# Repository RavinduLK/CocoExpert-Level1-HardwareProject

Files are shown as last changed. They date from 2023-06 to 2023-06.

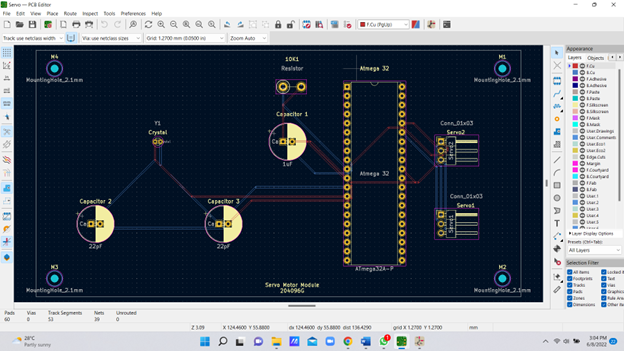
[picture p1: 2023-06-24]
Simulations/PCB Files/204096G-PCBs/204096G-PCBs'/PCB & Schematic Files-Servo/PCB Design-Screenshot.png

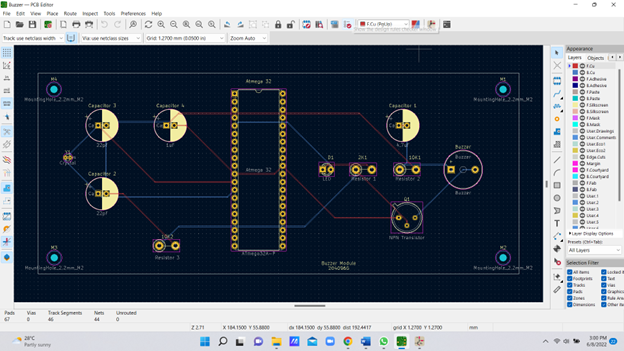
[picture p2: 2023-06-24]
Simulations/PCB Files/204096G-PCBs/204096G-PCBs'/PCB & Schematic Files-Buzzer/PCB Design-Screenshot.png

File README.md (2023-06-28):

# CocoExpert-Level1-HardwareProject
CocoExpert is an automated coconut breaking, scraping, and grinding machine with a focus on ensuring safety for housewives and frequent users, thereby eliminating the need for manual intervention

# Machine Animation Video
https://drive.google.com/drive/u/0/folders/18UEq-plaGjheWkudtf2PqrmO_yfCV39f

# Final Schematic Diagram
finale schematic diagram (2)

# Block Diagram


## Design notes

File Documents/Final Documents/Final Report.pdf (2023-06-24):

## Faculty of Information Technology

## IN 1900-ICT Project

## Automatic Coconut Breaking, Scraping, and Grinding Machine

Group No: 15

Nusky M.N.N. -204146L

Banu A.G.S. -204018X

Karunaweera R.L. -204096G

Kumarasingha H.J.A. -204108A

Lamahewage D.R. -204114M

Supervisor’s Name: BH Sudantha | Date of Submission: 01.10.2021

Dean/Senior lecturer

Dept. of Information Technology

Co-supervisor Name: Upulanka Premasiri

Lecturer

Dept. of Information Technology

Table of contents

Table of figures

Introduction

This project aims at designing an Automatic Coconut breaking, scraping, and grinding machine to

enable easy and safe extraction of milk from the coconut. Automation is one of the vital

developments which must be factored into our daily lives. The involvement of automation in the

cutting, scraping, and grinding of coconut is to improve the quality of these processes with less or

no human effort to save time and reduce the possibility of danger while cutting. There are some

existing products related to scrapping coconut in the market. In these products, there are some

limitations. Such as being unable to cut, scrape and grind the coconut in a single system. As we

are concerned about these limitations, we have come up with this machine as a solution.

Literature Survey

Traditional and Electric coconut graters

Scraping mechanism

Figure 1

This figure shows the manual coconut scraper which is used nowadays. Manually operated

coconut scraper machines are portable and may be used effectively in households, using the

clamping screw to clamp the entire mechanism securely on a table. As one rotates the manual handle,

the rotation is transferred to the scraping bit The DE husked coconut half-shell is pressed against the

sharp bit while in rotation. This device requires a fair amount of effort to grate a coconut. Attention is

required by the operator because if a slip occurs, serious injuries may result.

Figure 2

This figure shows the semi-automated coconut scraper. This machine is powered by a current,

and a switch is used to turn on and off the machine. The motor is used to rotate the scraper.

When using this machine, the operator should hold the coconut and the machine. So, in this machine also attention is required by the operator because if a slip occurs, serious injuries may

result.

Figure 3

Compared to the above two machines, the scraping part of our machine is very advantageous. Here

we use two scrapers. They work simultaneously. So, the time needed to scrap two coconuts is less

than the previous two machines. In those two machines, we should hold the coconut and the machine,

but in our scraper part, there is no need to hold the coconut and the machine. Coconuts are held by

the handles. This whole process is automated. Therefore, the operator's attention is not needed. So,

the user’s safety is confirmed.

Cutting mechanism

Figure 4

This figure shows the way we usually use to break the coconut. This is an unsafe and hard

mechanism. Also, here coconut water is wasted, and dust is spread everywhere.

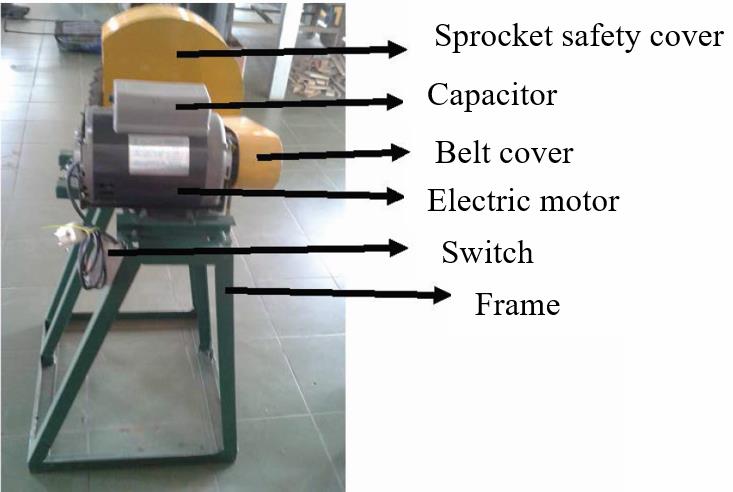
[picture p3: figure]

Figure 5

This coconut shell breaker is in the form of a box consisting of a breaking gear, and a coconut

clamp that can be adjusted according to the size of the coconut. The working principle of this

tool is the incorporation of the clamping, pressing, and shifting processes according to the

coconut fiber cutting path. The drive coconut shell breaker blade is driven by an electric motor

whose rotation has been reduced to produce a large torque. Coconut shells are the hardest part of

coconut fruit. Therefore, this shell breaker has several parts, including a sprocket safety cover,

capacitor, belt cover, electric motor as drive, switch on/off, coconut shell breaker sprocket,

coconut shell breaker and breaker, gearbox, and screw adjuster.

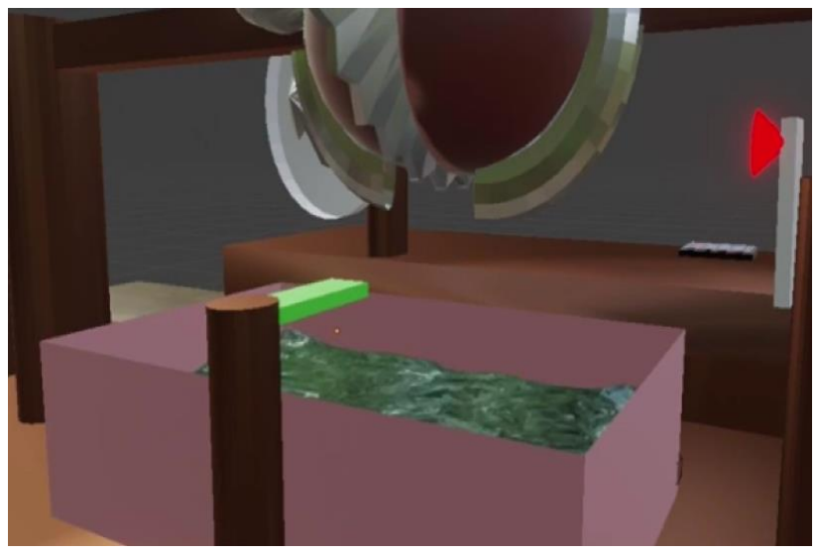
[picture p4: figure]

Figure | Figure 7 6

When compared to figure 4 the coconut breaking part of our machine is safer and easier. It is a

fully automated process. When compared to figure 5 the coconut breaking part of our machine

takes less space. Also, our breaking part is less complex. The start and end process in figure 5 is

manual but in our machine, we automated the ending process using an IR sensor. When

considering both figures 4 and 5 in our machine there is a systematic way to collect coconut

water and there is a cover to avoid coconut dust.

Also in the scrapping process, we use a color sensor. It helps to prevent the scrapping of the

coconut shell. That is also another advantage.

Summary

In our “automatic coconut breaking, scraping, and grinding machine” we improved coconut

breaking and scraping processes both by safety side and easiness. The Blender system is also

connected to the machine. Then the whole process can be done through the same machine, and it

will be very easy in our day-to-day life. The innovative automatic coconut breaking, scraping,

and grinding machine is time-saving, less power-consuming, has no need for manpower, and is

safe. It can break, scrape and grind coconuts within minutes. Also, it is portable and simple. The

coconut will be broken, scraped, and grinded automatically. The materials used for making this

machine are safe and cheap. So, among all these machines we can say our one is the most

effective machine.

Aim and objectives

Aim

- Design and develop an automated machine for the process of coconut breaking, scraping

& grinding with safety mechanisms.

Objectives

- To break the coconut and get the water separately.
- To scrape the coconut.
- To grind the coconut.
- To maintain the process safely.

Process Inputs | Outputs

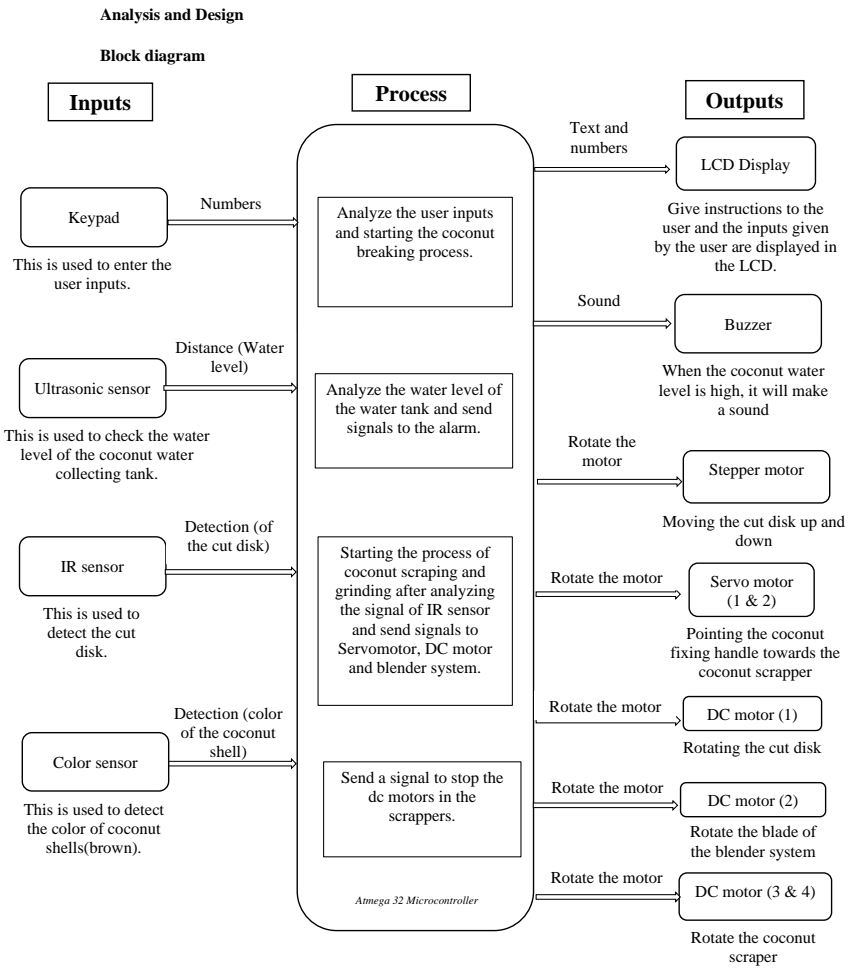
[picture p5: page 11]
Block diagram; Text and numbers; LCD Display; Atmega 32 Microcontroller; Keypad; Analyze the user inputs; Numbers; Give instructions to the; This is used to enter the; the LCD.; user inputs.; Buzzer; Sound; Distance (Water level); Ultrasonic sensor; a sound; Rotate the motor; Stepper motor; Color sensor; IR sensor; Servo motor (1 & 2); down; DC motor (3 & 4)

Analysis and Design

and starting the coconut
breaking process.

user and the inputs given
by the user are displayed in

When the coconut water
level is high, it will make

Analyze the water level of
the water tank and send
signals to the alarm.

This is used to check the water
level of the coconut water
collecting tank.

Detection (of
the cut disk)

Moving the cut disk up and

Starting the process of
coconut scraping and
grinding after analyzing
the signal of IR sensor
and send signals to
Servomotor, DC motor
and blender system.

Rotate the motor

This is used to
detect the cut
disk.

Pointing the coconut
fixing handle towards the
coconut scrapper

Detection (color
of the coconut
shell)

DC motor (1) Rotate the motor

Rotating the cut disk

Send a signal to stop the
dc motors in the
scrappers.

DC motor (2) This is used to detect
the color of coconut
shells(brown).

Rotate the blade of
the blender system

Rotate the coconut
scraper

Schematic diagram

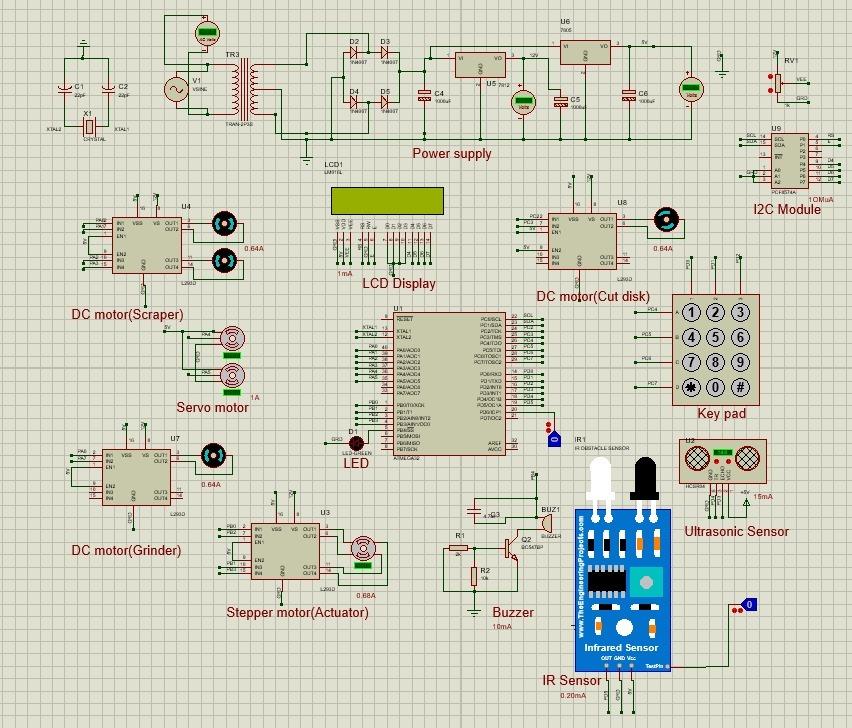
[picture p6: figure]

Figure 8 - Full schematic diagram

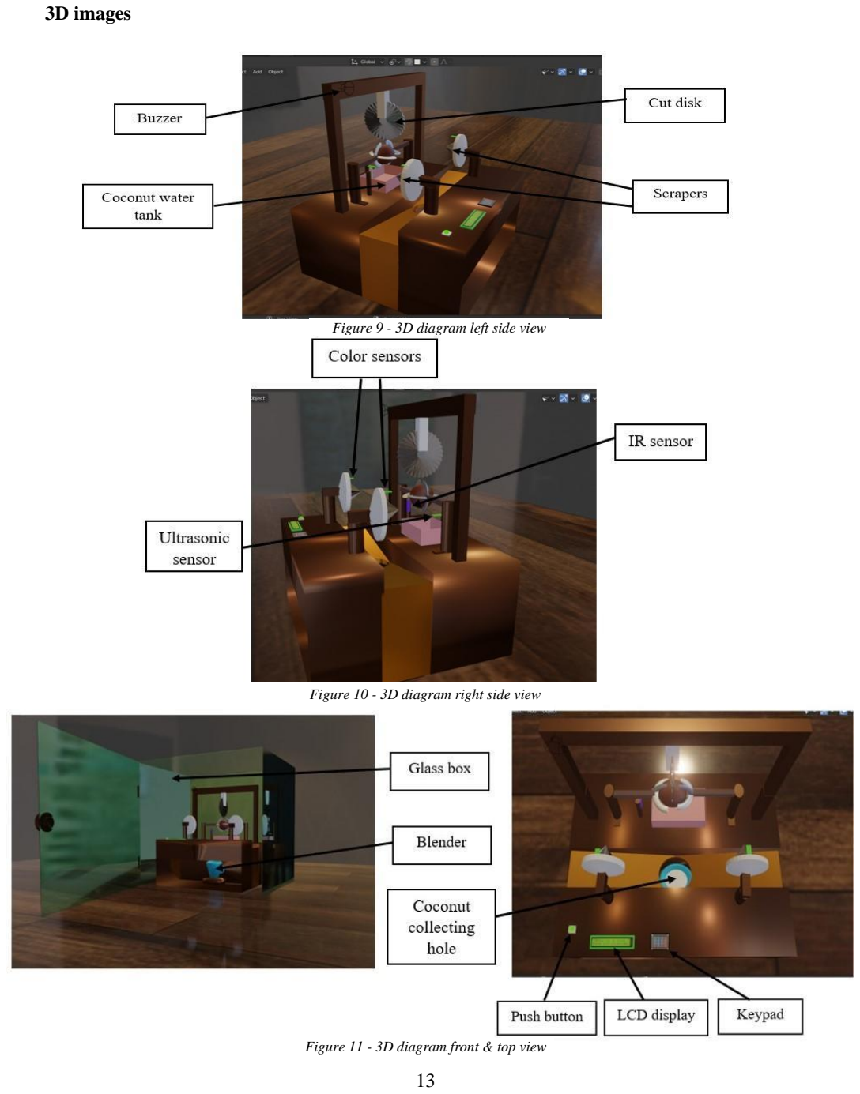
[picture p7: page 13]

3D images

Figure 9 - 3D diagram left side view

Figure 10 - 3D diagram right side view

Figure 11 - 3D diagram front & top view

Testing and Implementation

First, we should connect the machine to the power supply to power up the machine.

Using the push button user can start the machine. Once the machine starts the LCD displays the

below message.

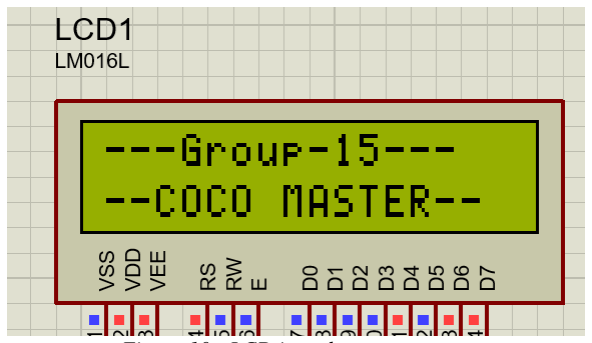
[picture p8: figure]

Figure 10 - LCD introductory message

Then the stepper motor and the DC motor begin to rotate clockwise simultaneously to break the

coconut. After the breaking part process is done, the IR sensor detects the cut disk and sends signals

to the stepper motor and the DC motor. Then only the stepper motor rotates anti-clockwise

direction and the dc motor stops rotating.

Figure 12 - Before rotating the stepper motor | Figure 11 - After rotating the stepper motor

Then the LCD will ask for the need for scraping. If scrapping is needed, the user should input

number 1 using the keypad. If not, the user should input number 2.

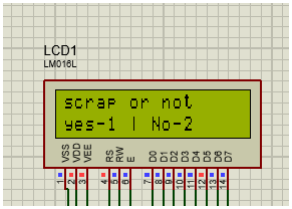
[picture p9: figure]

Figure 13 - LCD message 2

When the user inputs number 1, the display will ask whether one coconut part or both parts need

to be scrapped.

Figure 14 - LCD message 3

If the user gives number 1, only one servo motor connected to the handle will turn by 90°. After

the servo motor rotates, one DC motor connected to the scraper will rotate.

Figure 16 - Before rotating the servo motor

Figure 15 - After rotating only one servo motor

If the user gives number 2, both servo motors connected to the handles will turn by 90°. After the

servo motors rotate, both DC motors connected to the scrapers will rotate.

Figure 18 - Before rotating both servo motors

While rotating the scrapers, the color sensor connected to the scraper will detect the coconut shell

color(brown). If the brown color is detected DC motors connected to the scrappers will stop

rotating. In our simulation we used a testing pin to show the process of the color sensor.

for the brown color we assigned binary 1. for the white color we assigned binary 0.

After the scrapping part is done, the LCD displays the below message.

Figure 19 - LCD message 4

After the DC motor stops, the LCD displays the below message asking the need of grinding.

Figure 20 - LCD message 5

Figure 17 - After rotating both servo motors

If the user inputs number 1, the LCD shows the below message. The user will be given time to add

water to the grinder.

Figure 22 - LCD message 6

According to the number of scraped coconut parts, the rotating time of the DC motor in the blender

system will automatically be set by the machine. After the given time, the DC motor rotating stops.

After the grinding process the ultrasonic sensor detects the coconut water level of the coconut

water collecting tank. If the distance between the ultrasonic sensor and coconut water level is very

low, the LED will blink, and the buzzer will make a sound. The LCD also displays the below

message. Then the machine will stop.

Figure 21 - LCD message 7

Figure 23 - End of the process (LCD message and LED)

Total cost estimation

Item | Quantity | Price (Rs) | Subtotal (Rs)
Atmega32 | 1 | 1100 | 1100
IR sensor | 1 | 150 | 150
Ultrasonic sensor | 1 | 350 | 350
Buzzer | 1 | 400 | 400
Keypad (4*3) | 1 | 260 | 260
Display (2*16) | 1 | 840 | 840
Push-button | 1 | 40 | 40
Servo motor | 2 | 600 | 1200
Stepper motor | 1 | 1000 | 1000
DC motor | 4 | 1250 | 5000
Finishing | 1 | 3000 | 3000
Color sensor | 1 | 1500 | 1500
Motor driver | 4 | 780 | 3120
I2C module | 1 | 340 | 340
Total | | | 18300

Further work

- In the scrapping part, color sensor detects only the coconut shell color and stops scrappers

because sometimes coconut can be left inside the coconut shell after stopping the scrappers.

So, coconut can be wasted. As a solution we propose another automated process for the

scrappers using servo motors. If the color sensor detects the coconut shell, scrappers will

change its angle and do the scraping process until the coconut runs out.

- Sometimes users will face difficulties using the keypad to enter inputs. So, we propose a

remote-control system as further work to enter inputs more easily.

- Because of the plastic cover dust will collect inside the machine. As a solution, we propose

an automated cleaning process to remove the dust which collects inside the machine.

References

[1] ADMIN, "atmega32avr," atmega32avr, 2015. [Online]. Available: https://atmega32-avr.com/speed-direction-control-stepper-motor-using-avr-microcontroller/amp/. (https://atmega32-avr.com/speed-direction-control-stepper-motor-using-avr-microcontroller/amp/) [Accessed 15 September 2021].
[2] B. Ayob, "Atmega32-avr," [Online]. Available: https://atmega32-avr.com/servomotor-control-using-avr-atmega32-microcontroller/. (https://atmega32-avr.com/servo-motor-control-using-avr-atmega32-microcontroller/)
[3] B. Ayob, "atmega32-avr," atmega32-avr, 25 April 2012. [Online]. Available: https://atmega32-avr.com/atmega-32-pinout/. [Accessed 29 September 2021].
[4] B. Earl, "ADAFRUIT," ADAFRUIT, 5 May 2014. [Online]. Available: https://learn.adafruit.com/all-about-stepper-motors. [Accessed 15 October 2021].
[5] E. Funda, "Engineering Funda," Engineering Funda, 24 May 2021. [Online]. Available: https://www.youtube.com/watch?v=awS93t-uX4Q. [Accessed 29 October 2021].
[6] Github, "Embedotronics," Embedotronics, 2021. [Online]. Available: https://github.com/Embedotronics/Atmega16-interfacing-with-LCD-in-4-bit-mode. [Accessed 26 October 2021].
[7] l. chandak, "ElectronicWings Homepage," ElectronicWings , 2018. [Online]. Available: https://www.electronicwings.com/avr-atmega/ultrasonic-module-hc-sr04-interfacing-with-atmega1632. (https://www.electronicwings.com/avr-atmega/ultrasonic-module-hc-sr04-interfacing-with-atmega1632.) [Accessed 23 October 2021].
[8] l. chandak, "ElectronicWings Homepage," ElectronicWings Homepage, 2018. [Online]. Available: https://www.electronicwings.com/avr-atmega/interfacing-lcd-16x2-in-4-bit-mode-with-atmega-16-32-. (https://www.electronicwings.com/avr-atmega/interfacing-lcd-16x2-in-4-bit-mode-with-atmega-16-32-.) [Accessed 16 September 2021].
[9] TUSHAR, "Embedds," Embedds, 2018. [Online]. Available: https://embedds.com/interfacing-dc-motor-to-atmega32/. [Accessed 25 September 2021].
[10] Unknown, "Wikipedia," Wikipedia, 21 August 2021. [Online]. Available: https://en.wikipedia.org/wiki/DC_motor. [Accessed 15 October 2021].

Figure 24 - Ultrasonic sensor

Individual contribution

Member 1: Nusky M.N.N. (204146L)

Responsible Part:

My responsible components are the Ultrasonic sensor module and LCD Display module. I have

done the designing of schematic diagrams, PCB designs, and C codes for the above two modules.

And I made the full code of our machine. Also, I contributed to making the reports, 3D design of

our machine and presentations as well.

### 1. Ultrasonic sensor

Technique:

In our project, we used ultrasonic sensor to identify whether coconut water tank overflow or not.

We fixed ultrasonic sensors in the 10 cm height above the tank. When a distance (height) below

15 cm, an ultrasonic sensor is given a signal to the buzzer, and it will be given to signal to the

display.

Specifications:

- Working voltage: 5V DC
- Working current: 15mA
- Distance range: 2 - 400cm
- Measuring angle: 15 degrees
- Trigger input pulse: 10 micro-seconds

Ultrasonic sensor

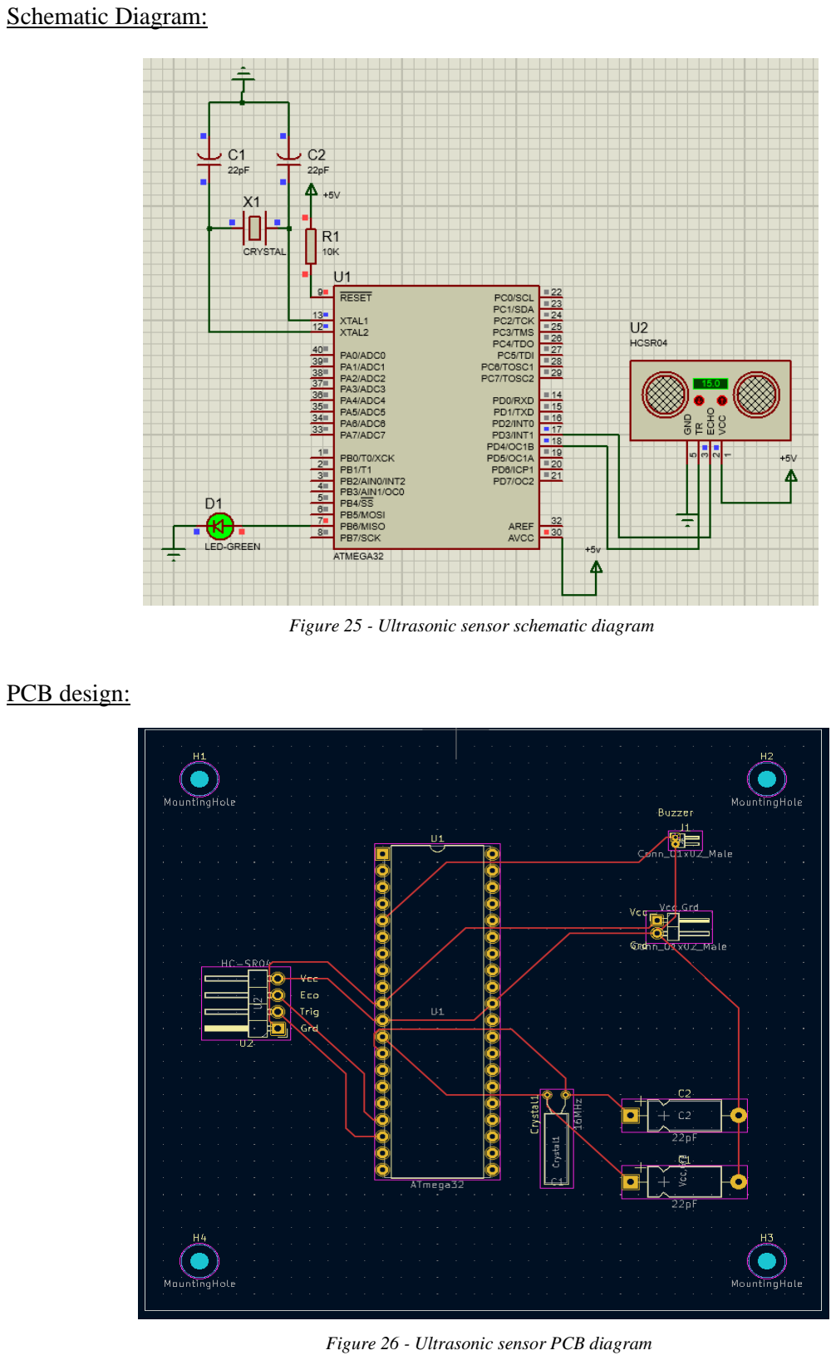
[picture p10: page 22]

Figure 25 - Ultrasonic sensor schematic diagram

Figure 26 - Ultrasonic sensor PCB diagram

Schematic Diagram:

PCB design:

Code:

#define F_CPU 8000000UL

#include <avr/interrupt.h> #include <util/delay.h>

#include <stdlib.h>

#include <avr/io.h>

static volatile unsigned int tCount = 0; static volatile int i = 0;
double distance = 0;
int main(void)
{

UBRRH=0x00;
UBRRL=51;
DDRB = DDRB | 1 << DDB6;
DDRD = DDRD | 1 << DDD4;
DDRD = DDRD & ~(1 << DDD3) ; PORTD = PORTD & ~(1 << PD3); _delay_ms(50);
GICR |= 1<<INT1;
MCUCR |= 1<<ISC10;
TIMSK |= 1 << TOIE1;
sei();
while(1)
{
PORTD = PORTD | 1<<PD4;
_delay_us(15);
PORTD = PORTD &
~(1<<PD4);
_delay_us(15);
distance =
tCount*1000000.0/F_CPU/58; if (distance < 15)
{
PORTB = PORTB | 1 <<
PB6;
}

else
{
PORTB = PORTB & ~(1 <<
PB6);
}
_delay_ms(200);
}
}
ISR(INT1_vect)
{
if(i == 0)
{
TCCR1B |= 1<<CS10;
i = 1;
}
else
{
TCCR1B = 0;
tCount = TCNT1;
TCNT1 = 0;
i = 0;
}
}

ISR(TIMER1_OVF_vect){
TCCR1B = 0;
tCount = 200;
TCNT1 = 0;
i = 0;
}

Figure 27

### 2. LCD display

Technique:

In our project we use a LCD display (16*2) for displaying what the process is at the time on our

machine and get the input from the user at a specific time.

E.g. | 1. Do you want to scrape?
| 2.How many parts scrape?
| 3.Do you want to grind?

Specification:

- Operating voltage of the LCD is 4.7V – 5.3V
- The utilization of current is 1mA with no backlight
- The display bezel is 72 x 25mm
- Number of columns – 16
- Number of rows – 2.
- It can display 32 characters at time

### 3. I2c Module (PCF8574A)

Technique:

In our project we used I2c module (PCF8574A) to reduce number of LCD pins which are

connected to the microcontroller with 2 pins.

Specification:

- Number of input outputs | -8
- Features | -Interrupt pin
- Supply voltage | -2.5V-6V
- Low standby-current consumption of 10 μA max.
- Addresses | -8
- Frequency (Max) | -100kHz
- Operating temperature range (C) | -40 to 85

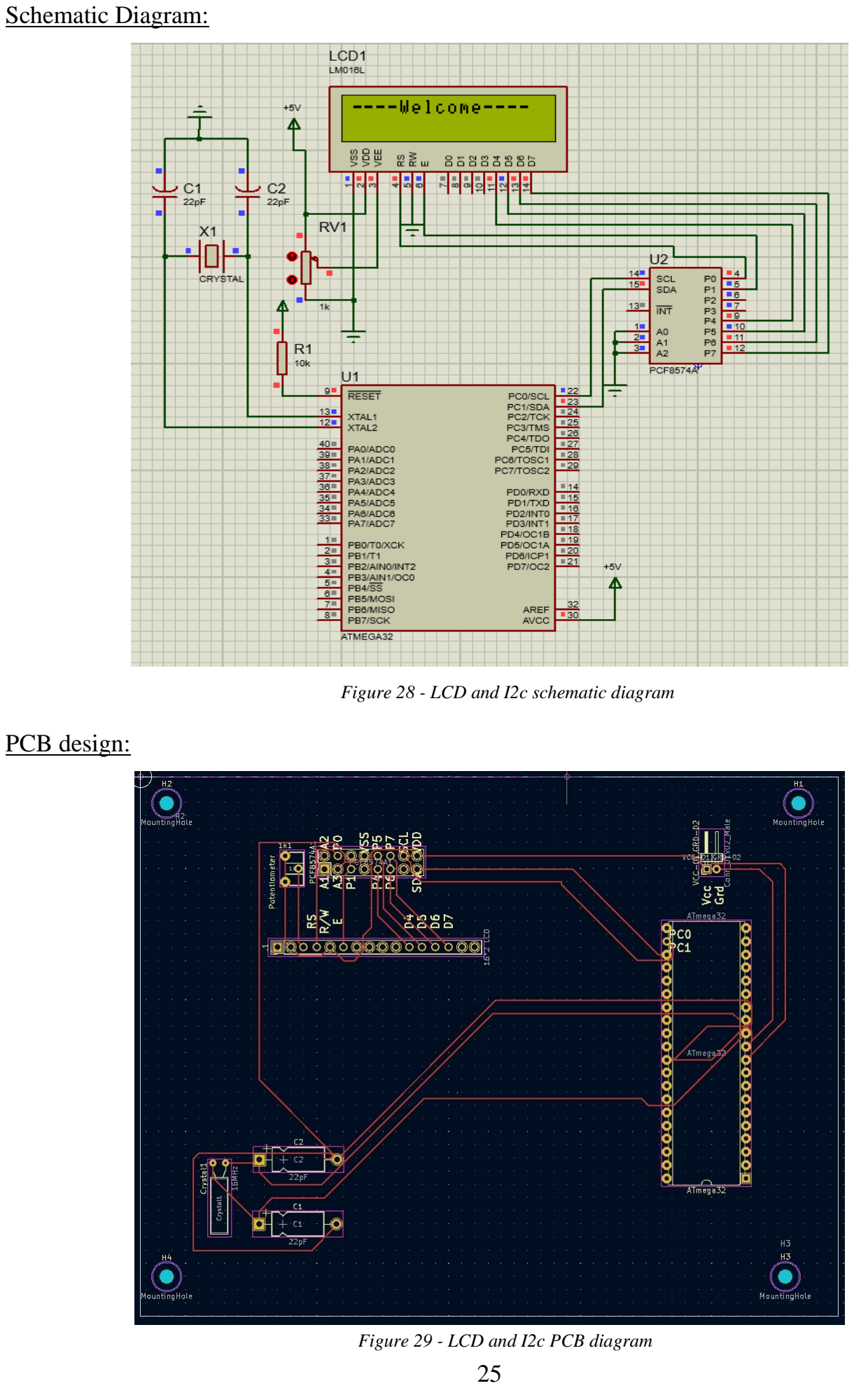
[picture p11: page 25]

Figure 28 - LCD and I2c schematic diagram

Figure 29 - LCD and I2c PCB diagram

Schematic Diagram:

PCB design:

Code:

#define F_CPU 8000000UL

#include <avr/io.h>

#include <util/delay.h>

#include "i2c.h"

#include "LCD_I2C.h"

int main(void)
{
i2c_init();
i2c_start();
i2c_write(0x70);
lcd_init();
while (1)

{
lcd_cmd(0x80);
lcd_msg("----Welcome----"); _delay_ms(1000);
lcd_cmd(0x01);
_delay_ms(100);
lcd_msg("scrap or not");
lcd_cmd(0xC0);
_delay_ms(200);
lcd_msg("yes-1 | No-2");
_delay_ms(1000);
lcd_cmd(0x01);
_delay_ms(200);
lcd_msg("How many parts?"); lcd_cmd(0xC0);
_delay_ms(200);
lcd_msg("One-1 | Two-2");
_delay_ms(1000);
lcd_cmd(0x01);
lcd_msg("--Thank you!--"); _delay_ms(1000);
lcd_cmd(0x01);
_delay_ms(1000);

}
}

Member 2: Banu AGS (204018X)

Responsible part:

- Designed, tested, and implemented steppe motor systems.
- designed the power supply system
- used the blender software to create the animation of the machine

In our project I have took the responsibility of moving the cut disk by using a stepper motor and a

motor driver. I’ve used stepper motor as it has Flexibility and supplied a constant holding torque

without the need for the motor to be powered. I've designed the schematic diagram of power supply

and stepper motor using proteus software. And used Atmel studio to program the stepper motor.

To create the PCB designs for my modules I've used the Kicad software. And I've helped in 3D

design and animation of the machine using the Blender software.

### 1. Stepper motor

Technique:

We're using a NEMA-17 stepper motor to move the cut disk. When the stepper motor rotates

clockwise the cut disk system attached to the stepper motor shaft moves down towards the coconut.

After breaking the coconut, the IR sensor gives a signal to the stepper motor, and it will rotate anti-

clockwise. Then the cut disk moves upwards to the starting position.

Specifications:

- Working voltage – 12V
- Max current – 1.58A
- Holding torque -6.0kg-cm(85oz-in)
- step angle -200 steps/revolution
- Bi-polar stepper motor | Figure 30 - Stepper motor

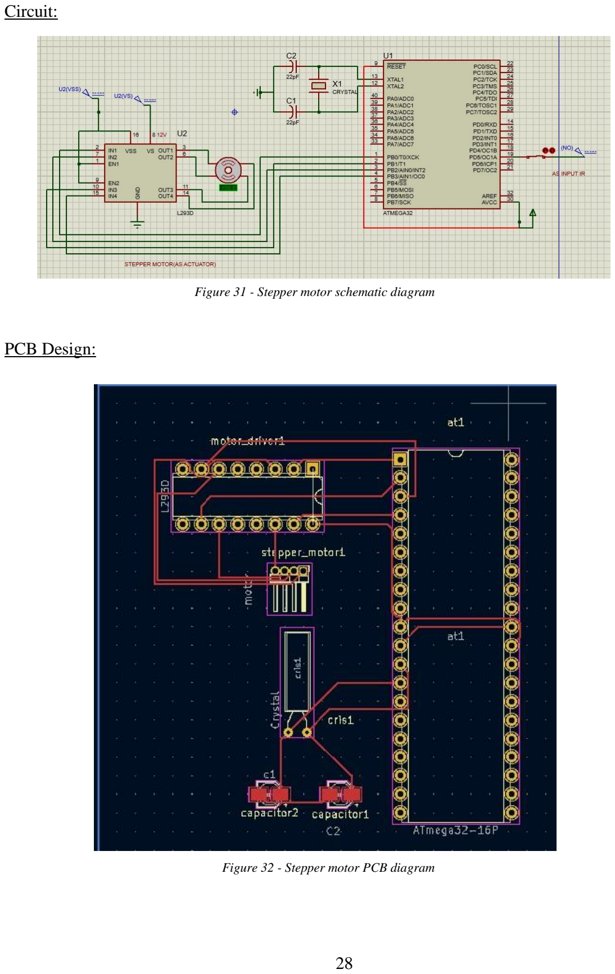
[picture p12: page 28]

Circuit:

PCB Design:

Figure 31 - Stepper motor schematic diagram

Figure 32 - Stepper motor PCB diagram

Code:

### 1. L293D Driver

Technique:

I have used an l293d driver to control the current flow through the stepper motor. Also, the

direction of this motor can be controlled independently.

Specification:

- Motor voltage Vcc2 (VS): 4.5V to 36V
- Supply Voltage to Vcc1(VSS): 4.5V to 7V
- Maximum Peak motor current: 1.6A
- Speed and Direction control is possible

#define F_CPU 8000000UL /* Define CPU Frequency 8MHz */

#include <avr/io.h> /* Include AVR std. library file */

#include <util/delay.h> /* Include delay header file */

int main(void)
{
int period=100;
DDRB |= 0B00001111;// making pins as output for stepper motor
DDRD &= ~(1<<5) ; //AS IR INPUT
while (1)
{
/* Rotate Stepper Motor clockwise*/ if(!(PIND & 0b00100000)) // ir not detected {
//power each winding in order to rotate PORTB = 0B00001000;
_delay_ms(period);
PORTB = 0B00000100;
_delay_ms(100);
PORTB = 0B00000010;
_delay_ms(100);
PORTB = 0B00000001;
_delay_ms(period);
}

/* Rotate Stepper Motor Anticlockwise */ else if((PIND & 0b00100000)) // ir detected {
for(int i=0;i<25;i++)
{PORTB = 0B00000001;
_delay_ms(period);
PORTB = 0B00000010;
_delay_ms(period);
PORTB = 0B00000100;
_delay_ms(100);
PORTB = 0B00001000;
_delay_ms(period);}
}
}
}

### 1. Power supply

Technique:

In our project we’re using a power supply system to power up the components. I have used an ac

step down transformer to convert ac 240v to 20v as our system requires a maximum voltage of

12V (to overcome current fluctuation issues I've taken 20V). Then used a rectifier circuit with 4

diodes to rectify the AC output from the transformer to DC. The capacitor is used as a filter to

remove the ripples from the rectified DC signal. Ripples are AC components in the DC signal.

Capacitor filters those AC components and provides a stable DC. I’ve used voltage regulators to

provide the regulated output. In our project we need only 5v and 12v, so I selected 7805,7812

regulators to fill the requirements.

Circuit:

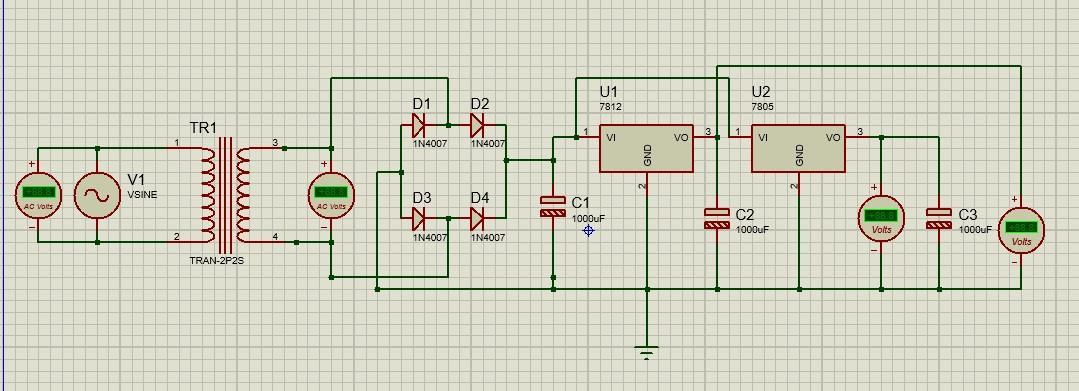
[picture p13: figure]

PCB Design:

Figure 33 - Power supply schematic diagram

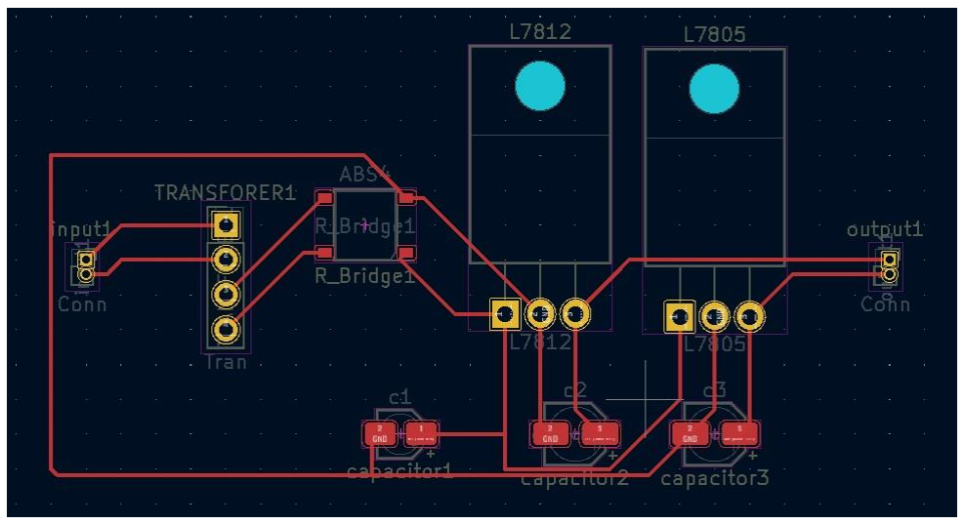
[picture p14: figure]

Figure 34 - Power supply PCB diagram

Member 3: Karunaweera R.L. (204096G)

Responsible Part:

My responsible components are the servo motor module and buzzer module. I have done the

designing of schematic diagrams, PCB designs, and C codes for the above two modules. And I

made the full PCB design of our machine. Also, I contributed to making the reports, presentations,

and presenting as well.

### 1. Servo Motor

Technique:

Servo motor controls the fixing handles and points the coconut fixing handle towards the scraper

by turning it by 90 degrees and holding it thereafter coconut breaks till the coconut scraping is

finished as you can see in the below figures. And I selected SG Tower pro 90 Motor for our project.

Figure 36

Specifications:

- The operating Voltage is +5V typically.
- Torque is 2.5kg/cm.
- The operating speed is 0.1s/60°.
- Gear Type is Plastic.
- Rotation is 0°-180°.
- Weight of motor is 9gm.
- The package includes gear horns and screws.

Figure 35

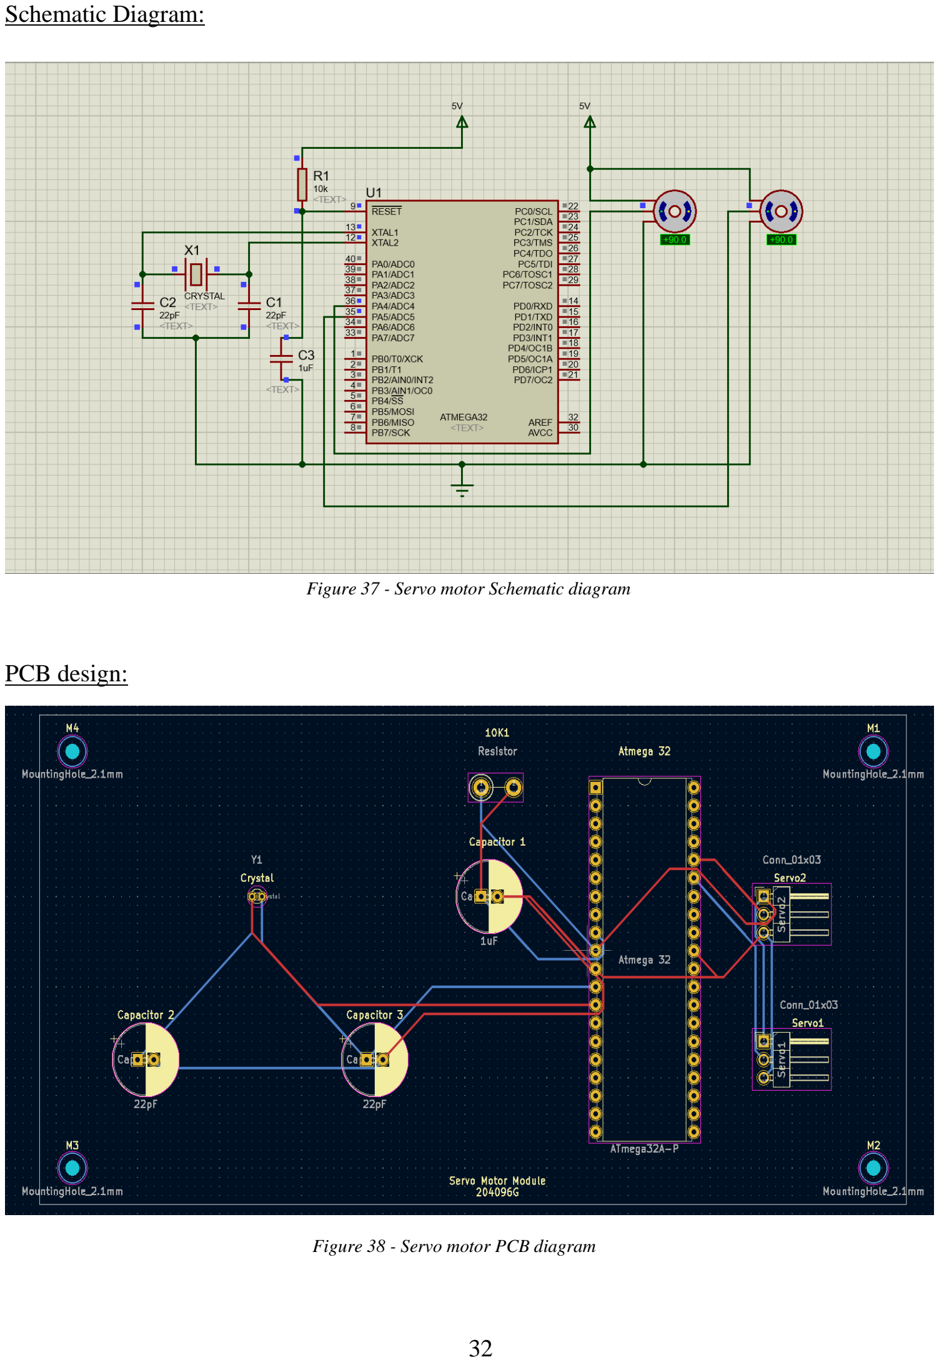
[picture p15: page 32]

Schematic Diagram:

PCB design:

Figure 37 - Servo motor Schematic diagram

Figure 38 - Servo motor PCB diagram

Codes:

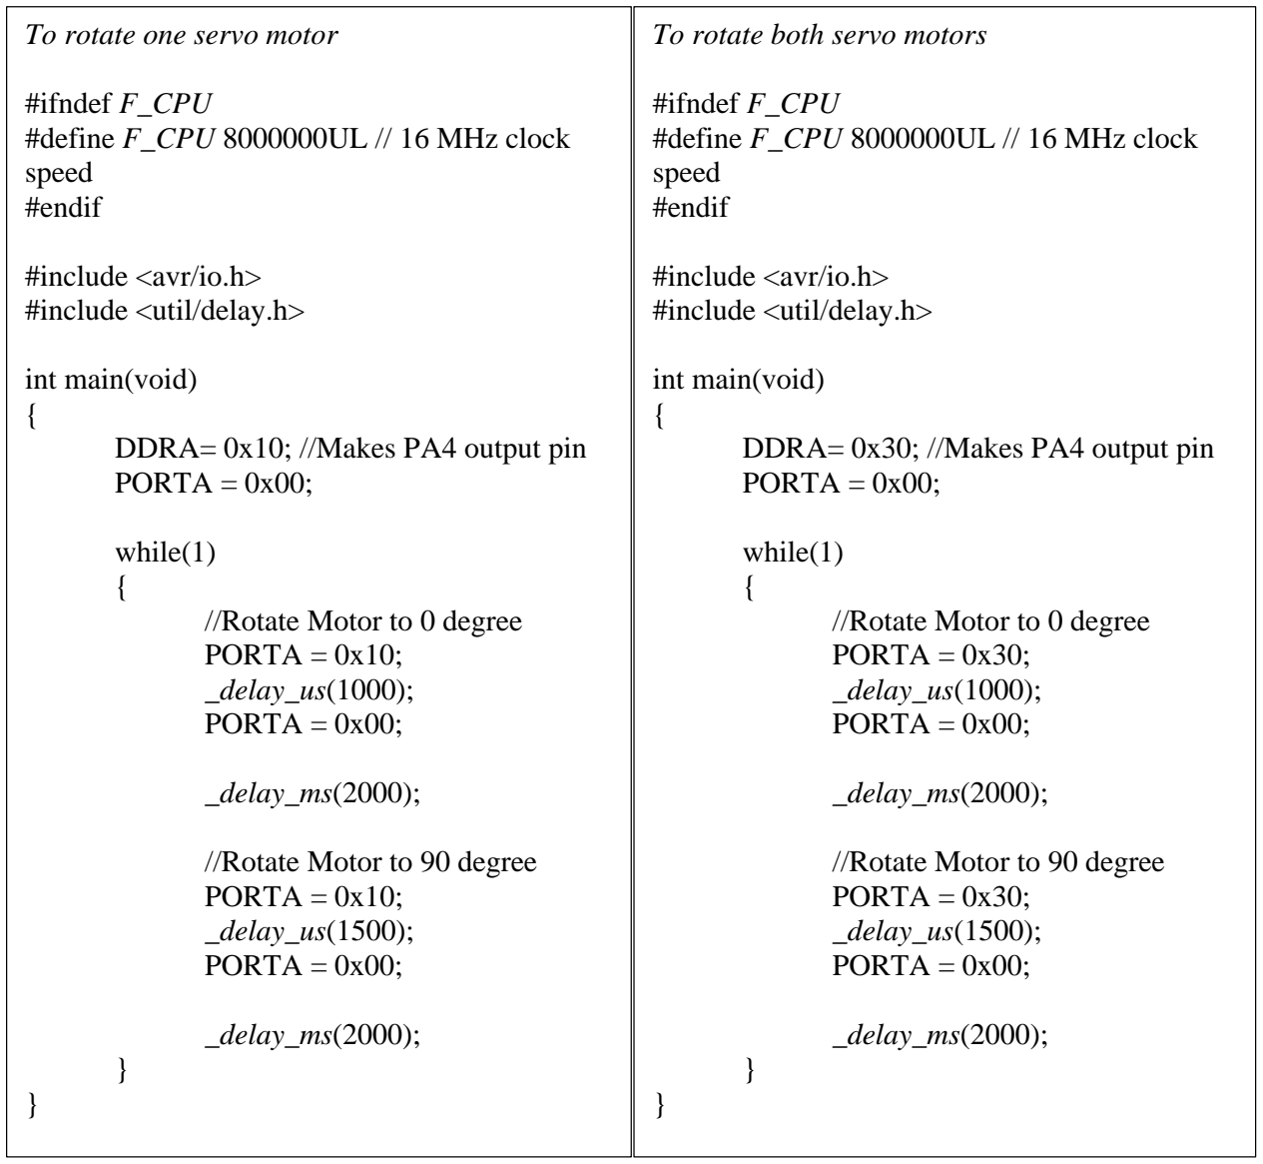
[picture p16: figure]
Figure; To rotate one servo motor; #ifndef F_CPU #define F_CPU 8000000UL // 16 MHz clock speed #endif; #include <avr/io.h> #include <util/delay.h>; int main(void) {; DDRA= 0x10; //Makes PA4 output pin PORTA = 0x00;; while(1) {; //Rotate Motor to 0 degree PORTA = 0x10; _delay_us(1000); PORTA = 0x00;; _delay_ms(2000);; //Rotate Motor to 90 degree PORTA = 0x10; _delay_us(1500); PORTA = 0x00;; To rotate both servo motors; DDRA= 0x30; //Makes PA4 output pin PORTA = 0x00;; //Rotate Motor to 0 degree PORTA = 0x30; _delay_us(1000); PORTA = 0x00;; //Rotate Motor to 90 degree PORTA = 0x30; _delay_us(1500); PORTA = 0x00;

### 2. Buzzer

Technique:

The purpose of using the buzzer in our machine is to notify the user if the coconut water tank is

full. So based on the signal of the ultrasonic sensor it will ring. If the ultrasonic sensor senses the

water level is high, then it will send a signal through the microcontroller and the buzzer will start

to ring. That is shown in the below picture.

Specifications:

- Rated Voltage is 6V DC
- Operating Voltage is 4-8V DC
- Rated current is less than 30mA
- Sound Type is Continuous Beep
- Resonant Frequency is 2300 Hz

Figure 39

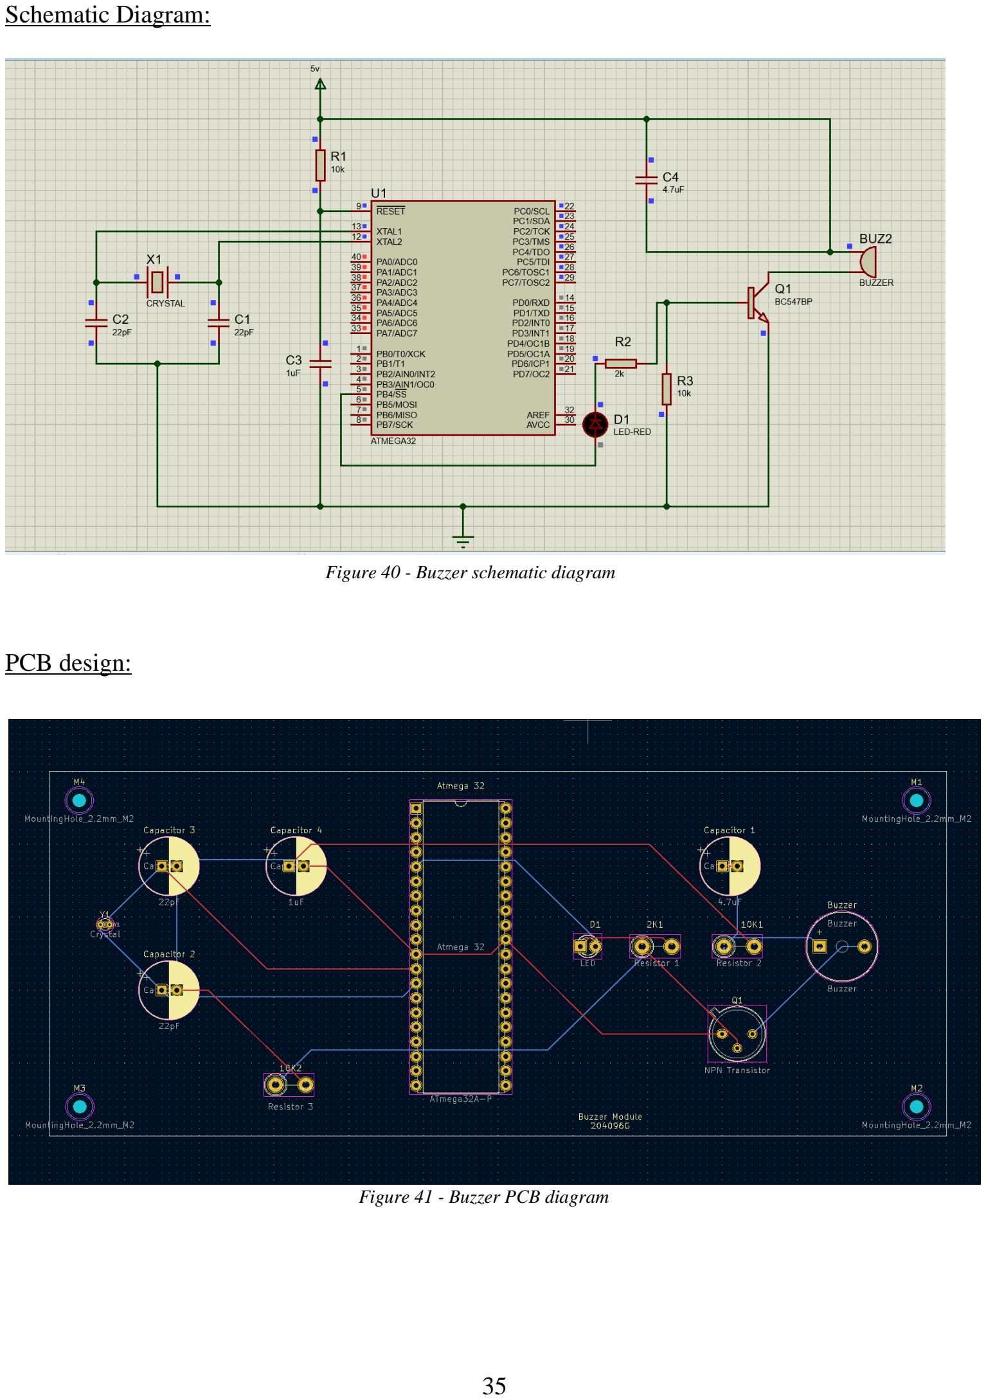
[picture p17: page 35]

Schematic Diagram:

PCB design:

Figure 41 - Buzzer PCB diagram

Figure 40 - Buzzer schematic diagram

Compiled Code:

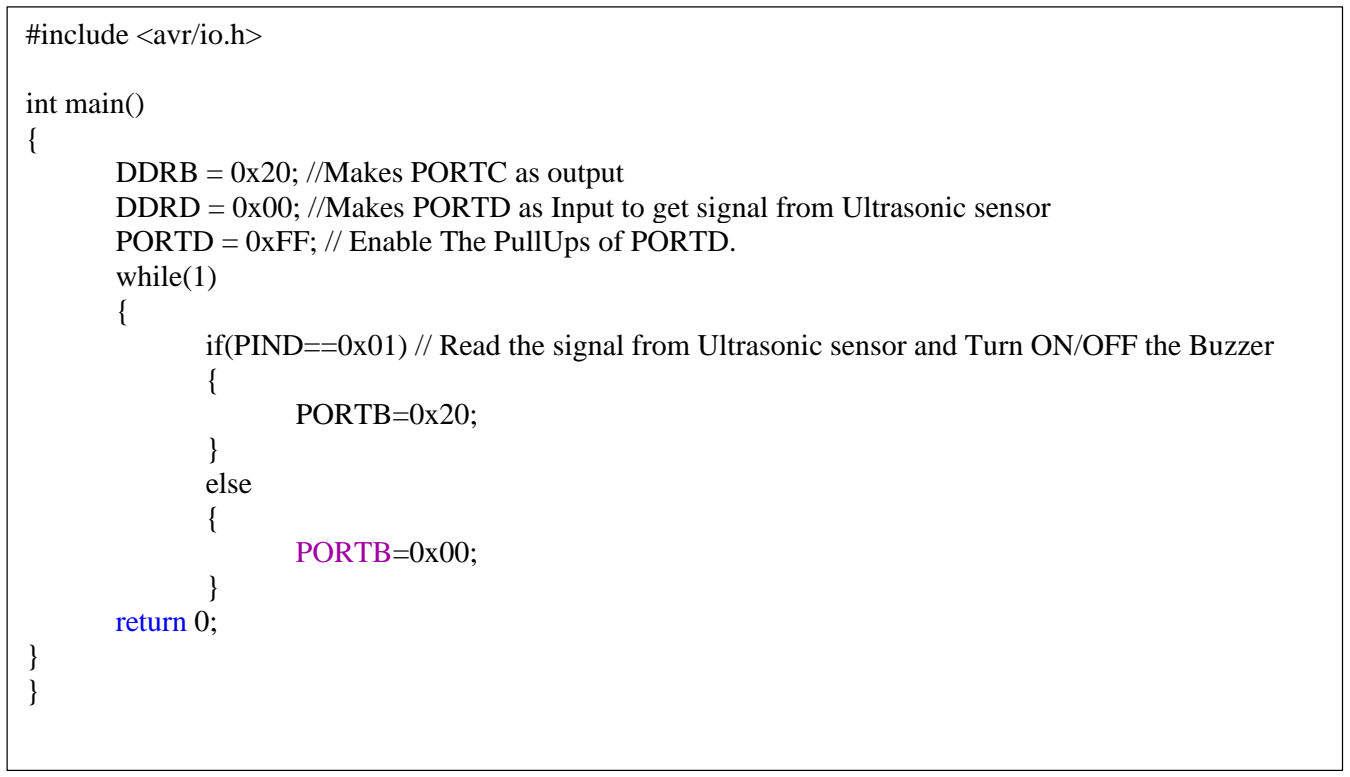
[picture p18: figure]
Figure; #include <avr/io.h>; int main() {; DDRB = 0x20; //Makes PORTC as output; while(1) {; PORTB=0x20;; } else {; PORTB=0x00;; } return 0;

DDRD = 0x00; //Makes PORTD as Input to get signal from Ultrasonic sensor PORTD = 0xFF; // Enable The PullUps of PORTD.

if(PIND==0x01) // Read the signal from Ultrasonic sensor and Turn ON/OFF the Buzzer

Member 4: Kumarasingha H.J. A. (204108A)

Responsible Part:

My responsible components are the DC motor module and color sensor module. I have done the

designing of schematic diagrams, PCB designs, and C codes for the above two modules. Also, I

contributed to making the reports, presentations, and presenting as well.

### 1. DC motor

Technique:

A dc motor converts direct current electrical energy into mechanical energy. The machine uses dc motors to rotate the cut disk, blender, and the scrappers by 360°
.There are 3 main types of dc

motors. dc shunt motor, dc series motor and dc compound motor. The shunt motor is more suitable

for the scrappers because the speed of a dc shunt motor is sufficiently constant. A compound dc

motor is more suitable for cut disk because compound motors provide high starting torque and

good speed regulation.

Specifications:

- Maximum Voltage - 12V
- Maximum Current - 0.64A
- Rated Speed (RPM) -200
- Rated Torque(kg-cm) -1.5
- Stall Torque(kg-cm) - 5.4

Circuit:

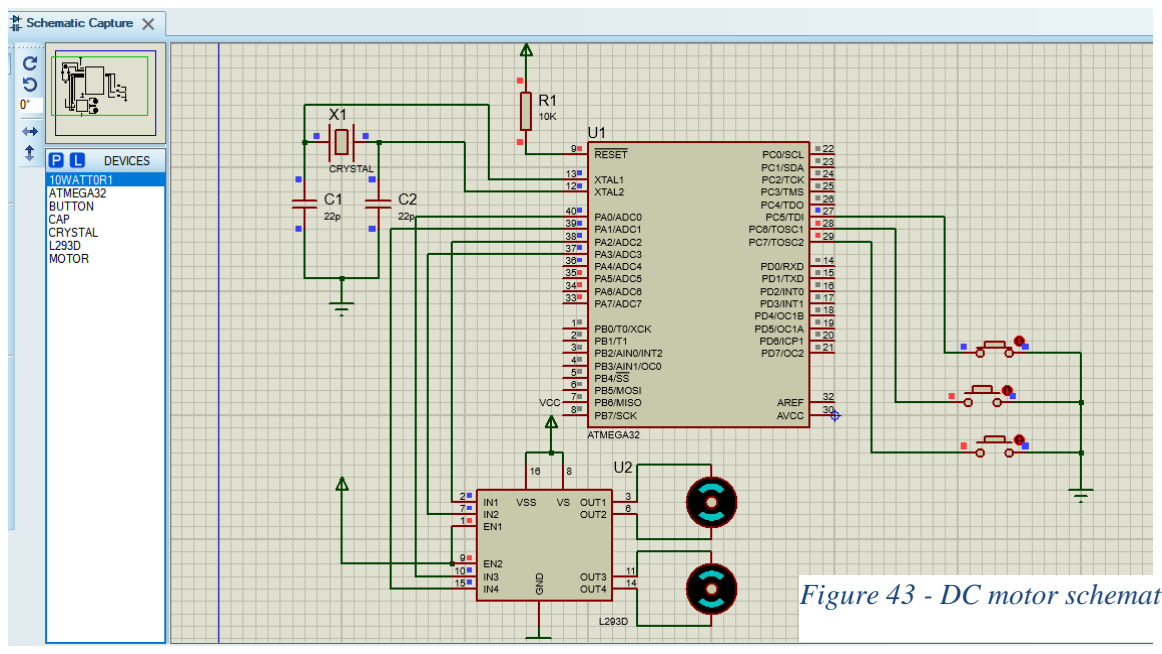
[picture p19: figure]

Figure 43 - DC motor schematic diagram of scrapers

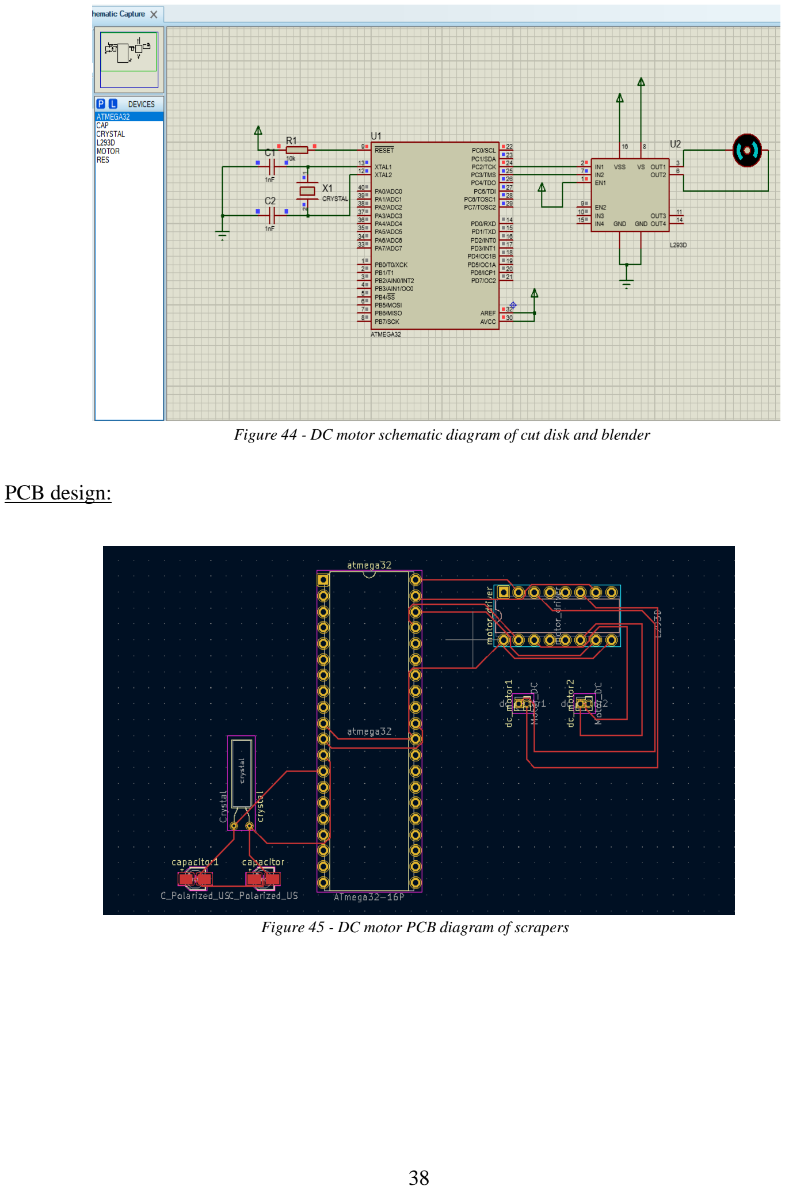
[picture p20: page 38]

PCB design:

Figure 44 - DC motor schematic diagram of cut disk and blender

Figure 45 - DC motor PCB diagram of scrapers

Figure 46 - DC motor PCB diagram of cut disk and blender

Code:

// code for the scrapers

#include <avr/io.h>

#define F_CPU 16000000UL

#include "util/delay.h"

//Test the PINC7
#define white_both (PINC&0b10000000) //Test the PINC6

#define brown (PINC&0b01000000) //Test the PINC5

#define white_one (PINC&0b00100000) //OUTPUT DATA FOR MOTOR

#define run_both 0b11100101

#define stop_running 0b11100000 #define run_one_motor 0b11100001 int main(void){

DDRA=0b00011111;//PINC7.5 INPUT PORTC=0b11100000; //PC7.5 SET TO HIGH while (1) {
if (white_both==0){
PORTA=stop_running;
_delay_ms(100);
PORTA=run_both;
}

else if (brown==0){
PORTA=stop_running;
_delay_ms(100);
PORTA=stop_running;
}
else if (white_one==0){
PORTA=stop_running;
_delay_ms(100);
PORTA=run_one_motor;
}
}

### 2. Color sensor

Technique:

It can Detect color of an object. Color converts the intensity of incident radiation into frequency.

This is used to detect the color of coconut shells(brown) in the

machine.

Specifications:

- Working voltage: 2.7 - 5.5v
- Working current: 1.4 mA
- Dimension: 28.4 x 28.4 mm
- Interface: digital TTL
- Weight: 4.17g
- Programmable color

// code for the cut disk and blender

#ifndef F_CPU

#define F_CPU 16000000UL // 16MHz clock speed #endif

#include <avr/io.h> //standard AVR library #include <util/delay.h> // delay library

int main(void){
DDRC= 0XFF; //direction of port B as output
while(1) // infinite loop{
PORTC= 0X05; //motor rotation in clockwise direction _delay_ms(2000); //delay of 2 sec

PORTC = 0X00; // motor stopped _delay_ms(2000); // delay of 2 sec }
}

Figure 47 - Color sensor

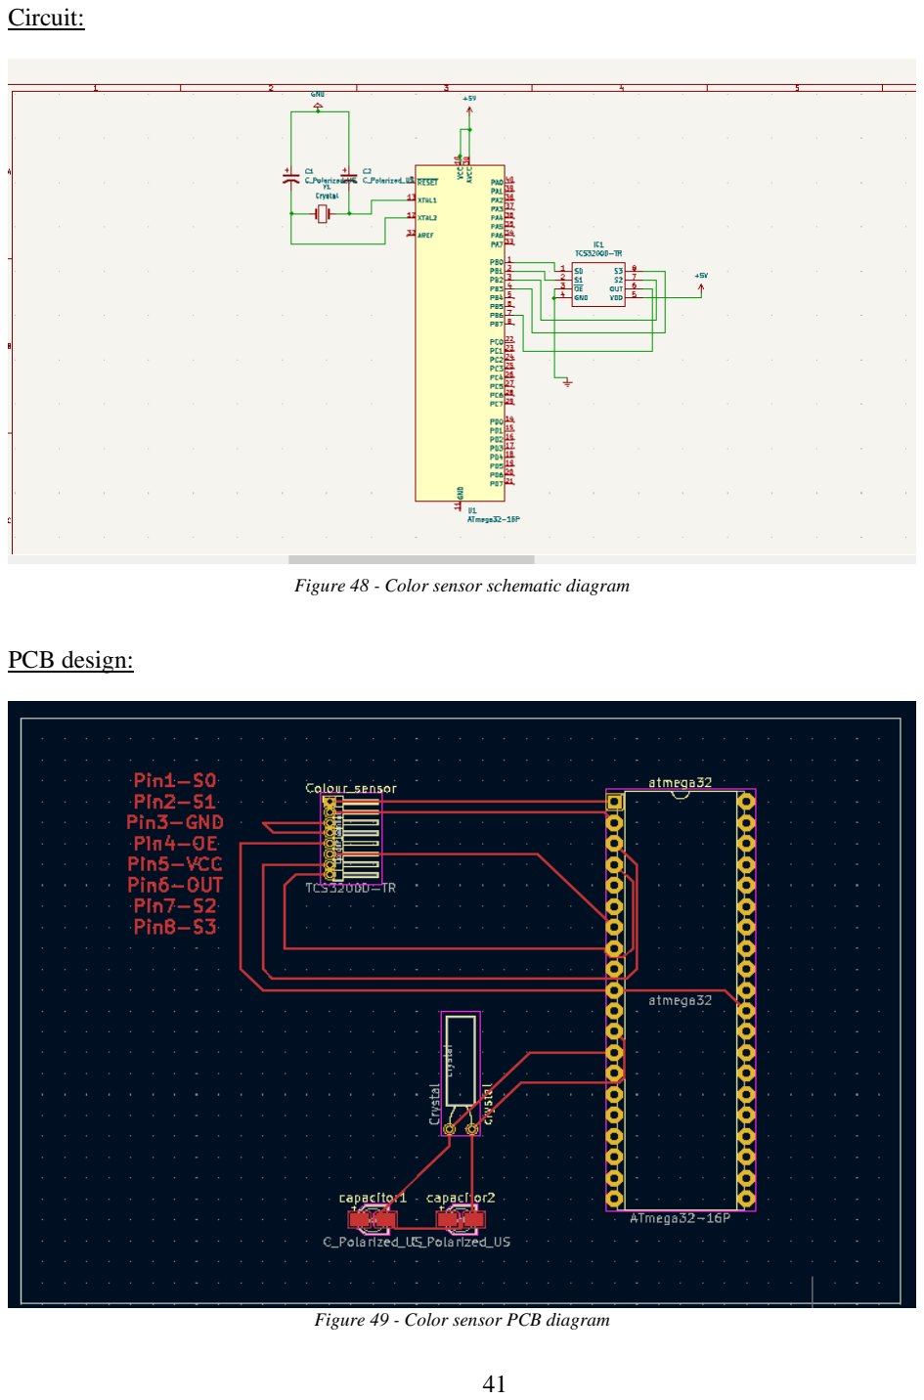
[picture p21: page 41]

Circuit:

PCB design:

Figure 48 - Color sensor schematic diagram

Figure 49 - Color sensor PCB diagram

Code:

#include <avr/io.h>

#include <util/delay.h>

#include "lib/colour_sensor/tcs3200.h"

uint32_t MeasureR(); //measure frequency with red filter uint32_t MeasureG(); //measure frequency with green filter uint32_t MeasureB(); //measure frequency with blue filter uint32_t MeasureC(); //measure frequency without filter int main(void){
InitTCS3200(); //Initialize TCS Library
uint8_t x=0;
int8_t vx=1;
while(1){
TCSLEDOn();
uint32_t v1=MeasureC();
delay_ms(100);

TCSLEDOff();
uint32_t v2=MeasureC();

uint32_t d=v1-v2;

if(d>8000) //detect colour change{ if(colour==red){
//stop motor
}
else if (colour==white){
//rotate motor
}
uint32_t r,g,b; //Show
TCSLEDOn();
r=MeasureR();
g=MeasureG();
b=MeasureB();
TCSLEDOff();
uint32_t smallest;

if(r<b){
if(r<g)
smallest=r;
else
smallest=g;
}

Else{
if(b<g)
smallest=b;
else
smallest=g;
}
uint32_t _r,_g,_b;
smallest=smallest/10; //decrease the smallest value with factor of 10 _r=r/smallest; //r, g, b are the value which have scaled
_g=g/smallest;
_b=b/smallest;
} } }
uint32_t MeasureR(){
TCSSelectRed();
uint32_t r;
_delay_ms(10);
r=TCSMeasure();
_delay_ms(10);
r+=TCSMeasure();
_delay_ms(10);
r+=TCSMeasure();
return r/3.3;
}
uint32_t MeasureG(){
TCSSelectGreen();
uint32_t r;
_delay_ms(10);
r=TCSMeasure();
_delay_ms(10);
r+=TCSMeasure();
_delay_ms(10);
r+=TCSMeasure();
return r/3;
}
uint32_t MeasureG(){
TCSSelectGreen();
uint32_t r;
_delay_ms(10);
r=TCSMeasure();
_delay_ms(10);
r+=TCSMeasure();
_delay_ms(10);
r+=TCSMeasure();
return r/3; }

### 3. L293D motor driver

Technique:

Output voltage and current of microcontroller is not sufficient to drive a dc motor. So, in the

machine l293d motor drivers provide up to 600mA current in the voltage range from 4.5 to 36V

to drive a dc motor.

Specifications:

- Wide Supply-Voltage Range: 4.5 V to 36 V
- Separate Input-Logic Supply
- Output Current :600 mA Per Channel
- High-Noise-Immunity Inputs

uint32_t MeasureB(){
TCSSelectBlue();
uint32_t r;
_delay_ms(10);
r=TCSMeasure();
_delay_ms(10);
r+=TCSMeasure();
_delay_ms(10);
r+=TCSMeasure();
return r/4.2; }

uint32_t MeasureC(){
TCSSelectClear();
uint32_t r;
_delay_ms(10);
r=TCSMeasure();
_delay_ms(10);
r+=TCSMeasure();
_delay_ms(10);
r+=TCSMeasure();
return r/3;
}
}

Figure 50 - Motor driver

Member 5: Lamahewage D. R. (204114M)

Responsible part:

My responsible components are the servo motor module and buzzer module. I have done the

designing of schematic diagrams, PCB designs, and C codes for the above two modules. Also, I

contributed to making the reports, presentations, and presenting as well.

### 1. IR sensor

Technique:

There are two LEDs. one of them emits IR Ray. the other receives IR rays. if that IR ray touches

any surface, it reflects. Then the reflected IR ray is caught by the IR receiver. then the sensor sends

a signal to fulfill our need. In our project, the IR sensor is

used to detect the cut disk.

Specifications:

- Working voltage: 3.6 - 5v
- Working current: 20mA
- Distance range: 2cm - 30cm
- Dimensions: 48 * 14 * 8 mm
- Weight: 15g

Circuit:

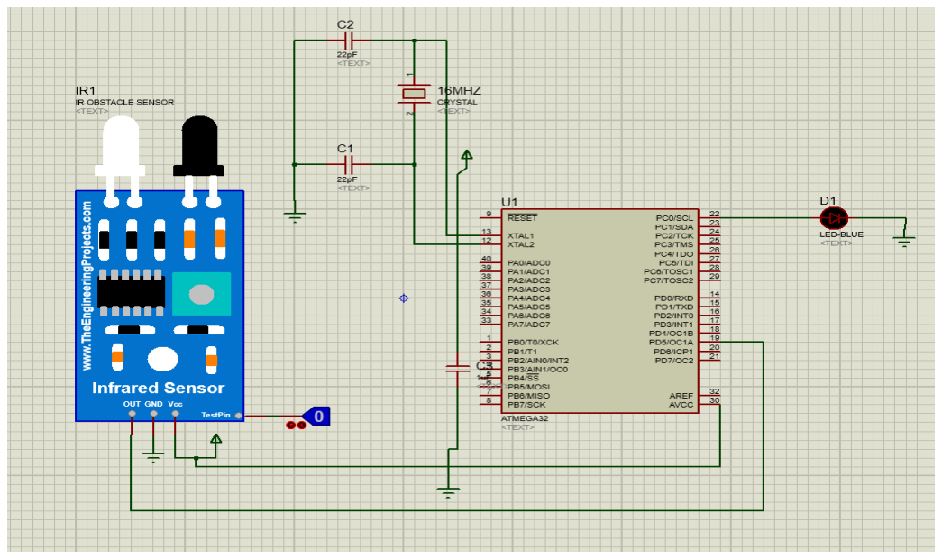
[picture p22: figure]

Figure 52 - IR sensor schematic diagram

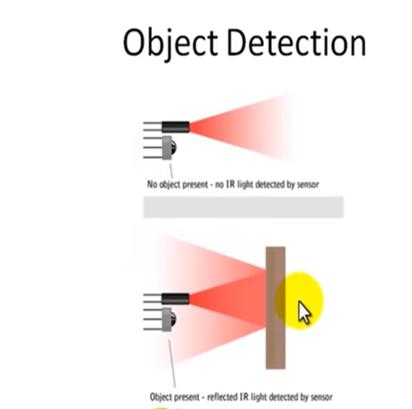
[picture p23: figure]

Figure 51

PCB design:

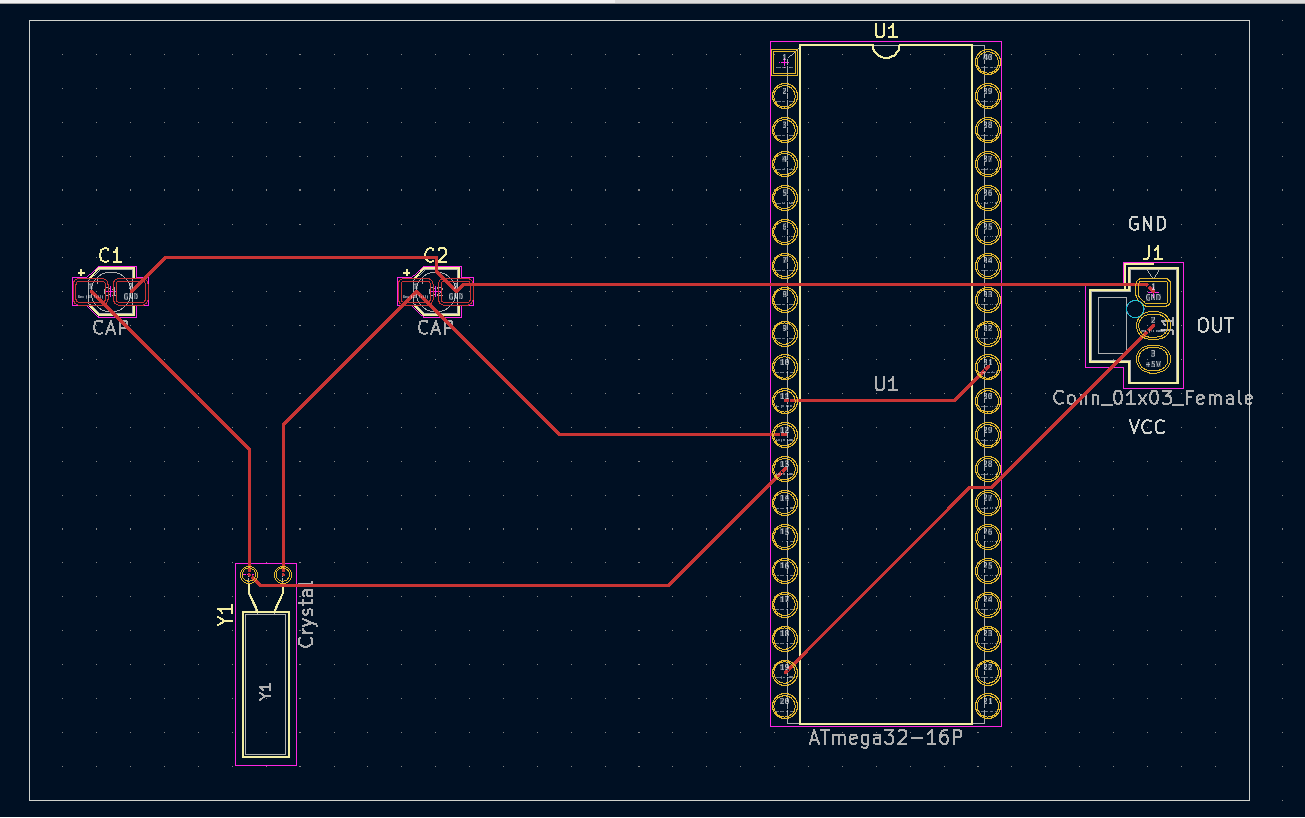
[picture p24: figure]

Code:

#define F_CPU 16000000UL

#include <avr/io.h>

int main(void)
{
DDRD=0x00;
DDRC=0xff;
while (1)
{
if(PINA==0x01)
{
PORTC=0x01;
}
else
{
PORTC=0x00;
}

}
}

Figure 53 - IR sensor PCB diagram

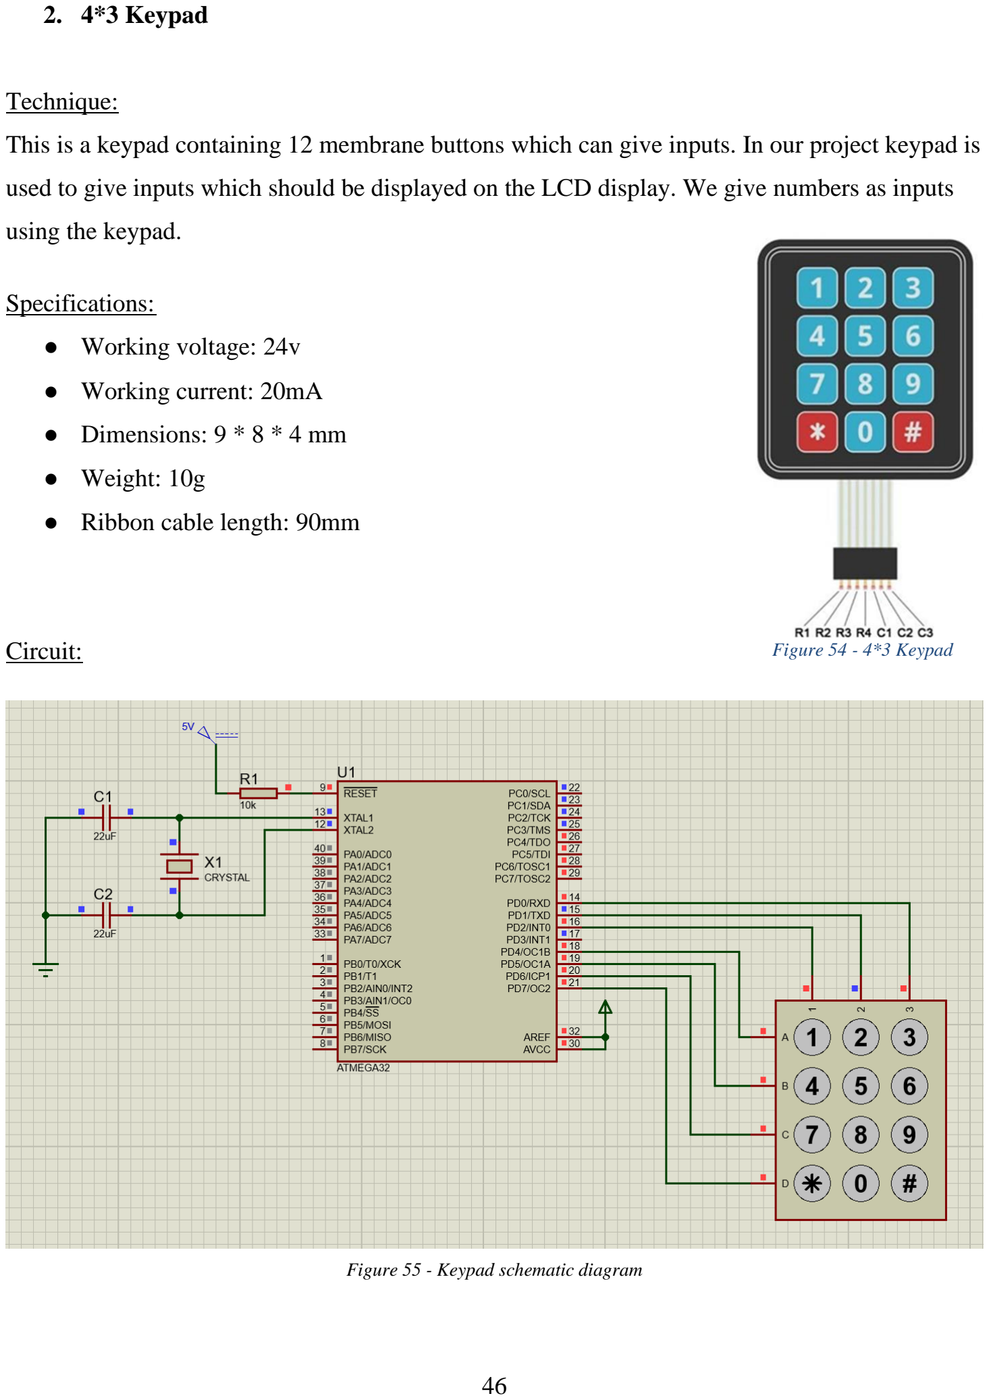
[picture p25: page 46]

2. 4*3 Keypad

Technique:

This is a keypad containing 12 membrane buttons which can give inputs. In our project keypad is

used to give inputs which should be displayed on the LCD display. We give numbers as inputs

using the keypad.

Specifications:

- Working voltage: 24v
- Working current: 20mA
- Dimensions: 9 * 8 * 4 mm
- Weight: 10g
- Ribbon cable length: 90mm
Circuit: | Figure 54 - 4*3 Keypad

Figure 55 - Keypad schematic diagram

PCB design:

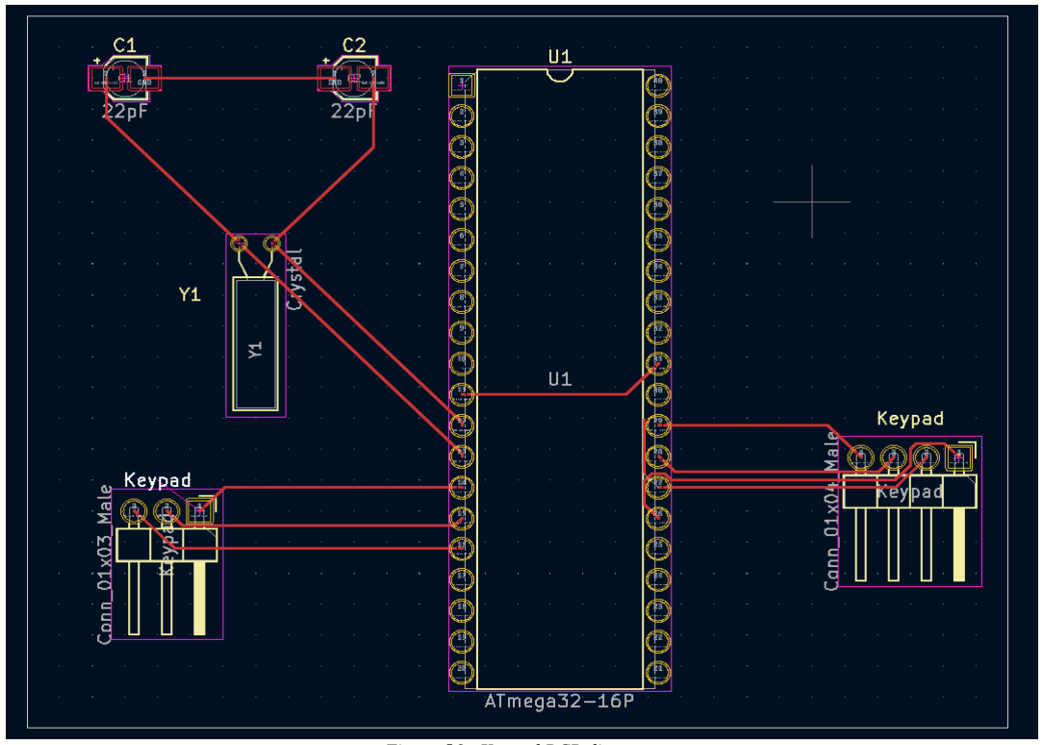
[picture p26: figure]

Figure 56 - Keypad PCB diagram

Code:

#define F_CPU 16000000UL

#include <avr/io.h>

#include <util/delay.h>

#include <avr/interrupt.h>

int main(void)
{
PORTC &=~ 0xf0 ; //PIN4-7 of port c is low PORTD |= ( 1<<0) ; //PIN0 of port D is high
PORTD |= ( 1<<1) ;
PORTD |= ( 1<<2) ;

PORTC |= 0b11100000; // make 1st row 0
PORTC &= ~ 0b00010000;
if((PIND & (1<<PIND0))==0){ _delay_ms(30);
return '1';
}else if((PIND &
(1<<PIND1))==0){
_delay_ms(30);
return '2';
}else if((PIND &
(1<<PIND2))==0){
_delay_ms(30);
return '3';
}
PORTC |=0b11010000;
PORTC &= ~ 0b00100000;
if((PIND & (1<<PIND0))==0){ _delay_ms(30);
return '4';
}else if((PIND &
(1<<PIND1))==0){
_delay_ms(30);
return '5';
}else if((PIND &
(1<<PIND2))==0){
_delay_ms(30);
return '6';
}

PORTC|=0b10110000;
PORTC &= ~ 0b01000000;
if((PIND & (1<<PIND0))==0){ _delay_ms(30);
return '7';
}else if((PIND &
(1<<PIND1))==0){
_delay_ms(30);
return '8';
}else if((PIND &
(1<<PIND2))==0){
_delay_ms(30);
return '9';
}
PORTC|=0b01110000;
PORTC &= ~ 0b10000000;
if((PIND & (1<<PIND0))==0){ _delay_ms(30);
return 'C';
}else if((PIND &
(1<<PIND1))==0){
_delay_ms(30);
return '0';
}else if((PIND &
(1<<PIND2))==0){
_delay_ms(30);
return '=';
}
}

void delay(int ms)
{
int i,j;
for(i=0;i<=ms;i++)
for(j=0;j<=120;j++);
}

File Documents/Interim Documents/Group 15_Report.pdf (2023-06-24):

## Faculty of Information Technology

## IN 1900-ICT Project

## Automatic Coconut breaking, scraping, and grinding machine

Group No: 15

Nusky M.N.N. -204146L

Banu A.G.S. -204018X

Karunaweera R.L. -204096G

Kumarasingha H.J.A. -204108A

Lamahewage D.R. -204114M

Supervisor’s Name: BH Sudantha | Date of Submission: 01.10.2021

Dean/Senior lecturer

Faculty of Information Technology

Signature of Supervisor:

ii

Table of Contents

iii

Table of figures

iv

Section 1: Introduction

This project aims at designing an Automatic Coconut breaking, scraping, and grinding machine to

enable easy and safe extraction of milk from coconut. Automation is one of the vital developments

which must be factored in our daily lives. The involvement of automation in the cutting, scraping,

and grinding of coconut is to improve the quality of these processes with less or no human effort

to save time, and reduce the possibility of danger while cutting. There are some existing products

related to scrapping coconut in the market. In these products there are some limitations. Such as

unable to cut, scrape and grind the coconut in a single system. As we concern about these

limitations, we have come up with this machine as a solution.


v

Section 2: Literature Survey

Traditional and Electric coconut graters

Scraping mechanism

Figure 1

This figure shows the manual coconut scraper which is used in nowadays. Manually – operated

coconut scraper machines are portable and may be used effectively in households, using the

clamping screw to clamp the entire mechanism securely on a table. As one rotates the manual handle,

the rotation is transferred to the scraping bit The DE husked coconut half-shell is pressed against the

sharp bit while in rotation. This device requires a fair amount of effort to grate a coconut. Attention is

required by the operator because if a slip occurs, serious injuries may result.

Figure 2

This figure shows the semi-automated coconut scraper. This machine is powered by current, and

a switch is used to on and off the machine. The motor is used to rotate the scraper. When using


vi

this machine operator should hold the coconut and the machine. So, in this machine also attention

is required by the operator because if a slip occurs, serious injuries may result.

Figure 3

In compared to above two machines the scraping part of our machine is very advantageous. Here we

use two scrapers. They work simultaneously. So, time needed to scrap two coconuts is less than

previous two machines. In those two machines we should hold coconut and the machine, but in our

scraper part no need to hold coconut and the machine. Coconuts are held by the handles. This whole

process is automated. Therefore, operator’s attention is no needed. So, the user’s safety is confirmed.

Cutting mechanism

Figure 4

This figure shows the way we usually use to break the coconut. This is an unsafe and hard

mechanism. Also, here coconut water is wasted, and dust is spread everywhere.


vii

Figure 5

This coconut shell breaker is in the form of a box consisting of a breaking gear, a coconut clamp

that can be adjusted according to the size of the coconut. The working principle of this tool is the

incorporation of the clamping, pressing, and shifting processes according to the coconut fiber

cutting path. The drive of the coconut shell breaker blade is driven by an electric motor which

rotation has been reduced to produce a large torque. Coconut shells are the hardest part of a

coconut fruit. Therefore, this shell breaker has several parts, including sprocket safety cover,

capacitor, belt cover, electric motor as drive, switch on/off, coconut shell breaker sprocket,

coconut shell breaker and breaker, gear box and screw adjuster.


viii

Figure 7


When compared to figure 4 the coconut breaking part of our machine is safer and easier. It is

fully automated process. When compared to figure 5 the coconut breaking part of our machine

takes less space. Also, our breaking part is less complex. Start and end process in figure 5 is

manual but in our machine, we automated ending process using IR sensor. When considering

both figure 4 and 5 in our machine there is a systematic way to collect coconut water and there is

a cover to avoid coconut dust.

Summary

In our “automatic coconut breaking, scraping, and grinding machine” we improved coconut

breaking and scraping processes both by safety side and easiness. Blender system is also

connected to the machine. Then the whole process can be done through same machine, and it

will be very easy in our day today life. The innovative automatic coconut breaking, scraping, and

grinding machine is really time saving, less power consuming, no need of manpower and safe. It

can break, scrape and grind coconuts within minutes. Also, it is portable and simple. The coconut

will be broken, scraped and grinded automatically. The materials used for making this machine

are safe and cheap. So, among all these machines we can say our one is the most effective

machine.

Figure 6

ix

Section 3: Problem in brief

- Hard & risky to break the coconut using knife with our hand.
- Difficult with scraping the coconut for a long time holding with the hands.
- Taking time to cut, scrape and grind the coconut separately.
- Have risk with handling the coconut through an unsafe machine.

Section 4: Aim and objectives

Aim

- Design and develop an automated machine for process of coconut breaking, scraping &

grinding with safety mechanism.

Objectives

- To break the coconut and get the water separately.
- To scrape the coconut.
- To grind the coconut.
- To maintain the process safely.

x

Section 5: System Description

We are using keypad, IR sensor, Ultrasonic sensor as the inputs. We are using keypad to input

how many parts user need to scrape using the machine, to input the need of grinding, to input the

time of grinding and resetting the details. We are using ultrasonic sensor to sense the water level

of the coconut water tank. Moreover, we are using the IR sensor to sense the cut disk and make

sure the coconut is broken properly. To get this done, we are using Atmega32 microcontroller.

When we consider about the outcomes, there are 2*16 digital display, alarm, servo motors, DC

motors, stepper motor and a grinder. We are using digital display to display the input data, alarm

system to give an alarm at finishing time. When we consider about the motors, DC motors will

do the coconut breaking alongside with a cut disk, scraping with a coconut scraper and also

grinding. And stepper motor will do the movement of the cut disk. And servo motor will make

the process of rotation of coconut fixing handle. Finally, there is a grinder to grind the scraped

coconut automatically.

Inputs | Process | Outputs

Block diagram; Keypad; Ultrasonic sensor; IR sensor; Display; Alarm; Servo motor Pointing the coconut fixing handle towards the coconut scraper; Blender system; Atmega 32 Microcontroller; Numbers; Distance (Water level); Rotate the motor; Sound; Text and numbers; Grinding

Analyze the user inputs
and starting the coconut
breaking process.

Stepper motor
Moving the cut
disk up and
down.

Analyze the water level
of the water tank and
send signals to the alarm.

DC motor
Rotating the cut
disk and
coconut scraper

Starting the process of
coconut scraping and
grinding after analyzing
the signal of IR sensor
and send signals to
Servomotor, DC motor
and blender system.

Detection (of
the cut disk)


xii

Figure 9 - Front view | Figure 10 - Right side view

3D images

Figure 8 - Overview

Display

Keypad

Alarm

Coconut
scraper
(DC
motor)

Coconut
fixing
handle
(Servo
motor)

Push
button

Coconut
water
tank

Cut disk
(DC
motor)

IR sensor

Ultrasonic
sensor

Blender

Glass
Box


xiii

Section 6: Testing and Implementation

Member 1 - Nusky M.N.N. (204146L)

Figure 11-LCD circuit diagram

Figure 12 - LCD C code


xiv

Figure 13 - Ultrasonic sensor circuit diagram

Figure 14 - Ultrasonic sensor C code


xv

Member 2 - Banu A.G.S. (204018X)

Figure 15 - Stepper motor circuit diagram

Figure 16 - Power supply


xvi

Figure 17 - Stepper motor C code


xvii

Member 3 – Karunaweera R.L. (204096G)

Figure 18 - Servo motor circuit diagram

Figure 19 - Servo motor C code


xviii

Figure 20 - Buzzer circuit diagram

Figure 21 - Buzzer C code


xix

Member 4 - Kumarasingha H.J.A. (204108A)

Figure 22 - DC motor circuit diagram

Figure 23 - DC motor C code


xx

Member 5 - Lamahewage D. R. (204114M)

Figure 24 - IR sensor circuit diagram

Figure 25 - Keypad circuit diagram


xxi

Figure 26 - IR sensor C code

Figure 27 - Keypad C code

xxii

Section 7: Resource Requirements

Software:

- Atmel Studio
- Blender
- Simulation software

Hardware:

- Microcontroller: Atmega32
- IR Sensor
- Ultrasonic sensor
- Keypad
- Alarm
- Display
- Stepper motor
- Servo motor
- DC motor
- Push button
- Blender system

xxiii

Section 8: Cost estimation

Item | Quantity | Price (Rs) | Subtotal (Rs)
Atmega32 | 1 | 540 | 540
IR sensor | 1 | 25 | 25
Ultrasonic sensor | 1 | 200 | 200
Alarm | 1 | 300 | 300
Keypad (4*4) | 1 | 160 | 160
Display (2*16) | 1 | 600 | 600
Push button | 1 | 10 | 10
Servo motor | 2 | 500 | 1000
Stepper motor | 2 | 1050 | 2100
DC motor | 3 | 1250 | 3750
Blender system | 1 | 3500 | 3500
Finishing | 1 | 4000 | 4000
Total | | | 16185

Table 1 - Estimated cost

xxiv

Appendix A - References

Section 9: References

[1] ADMIN, "atmega32avr," atmega32avr, 2015. [Online]. Available: https://atmega32-avr.com/speed-direction-control-stepper-motor-using-avr-microcontroller/amp/. (https://atmega32-avr.com/speed-direction-control-stepper-motor-using-avr-microcontroller/amp/) [Accessed 15 September 2021].
[2] B. Ayob, "Atmega32-avr," [Online]. Available: https://atmega32-avr.com/servo-motor-control-using-avr-atmega32-microcontroller/. (https://atmega32-avr.com/servo-motor-control-using-avr-atmega32-microcontroller/)
[3] B. Ayob, "atmega32-avr," atmega32-avr, 25 April 2012. [Online]. Available: https://atmega32-avr.com/atmega-32-pinout/. [Accessed 29 September 2021].
[4] B. Earl, "ADAFRUIT," ADAFRUIT, 5 May 2014. [Online]. Available: https://learn.adafruit.com/all-about-stepper-motors. [Accessed 15 October 2021].
[5] E. Funda, "Engineering Funda," Engineering Funda, 24 May 2021. [Online]. Available: https://www.youtube.com/watch?v=awS93t-uX4Q. [Accessed 29 October 2021].
[6] Github, "Embedotronics," Embedotronics, 2021. [Online]. Available: https://github.com/Embedotronics/Atmega16-interfacing-with-LCD-in-4-bit-mode. [Accessed 26 October 2021].
[7] l. chandak, "ElectronicWings Homepage," ElectronicWings , 2018. [Online]. Available: https://www.electronicwings.com/avr-atmega/ultrasonic-module-hc-sr04-interfacing-with-atmega1632. (https://www.electronicwings.com/avr-atmega/ultrasonic-module-hc-sr04-interfacing-with-atmega1632.) [Accessed 23 October 2021].
[8] l. chandak, "ElectronicWings Homepage," ElectronicWings Homepage, 2018. [Online]. Available: https://www.electronicwings.com/avr-atmega/interfacing-lcd-16x2-in-4-bit-mode-with-atmega-16-32-. (https://www.electronicwings.com/avr-atmega/interfacing-lcd-16x2-in-4-bit-mode-with-atmega-16-32-.) [Accessed 16 September 2021].
[9] TUSHAR, "Embedds," Embedds, 2018. [Online]. Available: https://embedds.com/interfacing-dc-motor-to-atmega32/. [Accessed 25 September 2021].
[10] Unknown, "Wikipedia," Wikipedia, 21 August 2021. [Online]. Available: https://en.wikipedia.org/wiki/DC_motor. [Accessed 15 October 2021].

xxv

Appendix B – Individual contribution

Section 10: Individuals Contribution to the Project

Name of student: Nusky M.N.N. (204146L)

1. Study basic microcontroller programming
2. Studying LCD and Ultrasonic sensor module
3. Programming LCD and Ultrasonic sensor module
4. Design simulation
5. Designing 3D image

Name of student: Banu A.G.S. (204018X)

1. Study basic microcontroller programming
2. Studying stepper motor module and power supply
3. Programming stepper motor module
4. Design simulation
5. Designing 3D image

Name of student: Karunaweera R.L. (204096G)

1. Study basic microcontroller programming
2. Studying servo motor module and buzzer module
3. Programming servo motor module and buzzer module
4. Design simulation
5. Designing 3D image

Name of student: Kumarasingha H.J. A. (204108A)

1. Study basic microcontroller programming
2. Studying DC motor module
3. Programming DC motor module
4. Design simulation
5. Designing 3D image

xxvi

Name of student: Lamahewage D. R. (204114M)

1. Study basic microcontroller programming
2. Studying IR sensor and Keypad modules
3. Programming IR sensor and Keypad modules
4. Design simulation
5. Designing 3D image

xxvii

Section 11: Action Plan (Appendix C)

| Responsible group member | Task | Duration | Start Date | End Date | Completion date
| | | | | | 24/01/2022 | 10/02/2021 | 10/02/2022 | 24/02/2022 | 10/03/2022 | 24/03/2022
1 | 204146L | Studying more about components and design circuit. | 4 weeks | 10/01/2022 | 10/02/2021
| | Design PCB and compile the code | 2 weeks | 10/02/2022 | 24/02/2022
| | Programming and testing | 4 weeks | 24/02/2022 | 24/03/2022
2 | 204018X | Studying more about components and design circuit. | 4 weeks | 10/01/2022 | 10/02/2021
| | Design PCB and compile the code | 2 weeks | 10/02/2022 | 24/02/2022
| | Programming and testing | 4 weeks | 24/02/2022 | 24/03/2022
3 | 204096G | Studying more about components and design circuit. | 4 weeks | 10/01/2022 | 10/02/2021
| | Design PCB and compile the code | 2 weeks | 10/02/2022 | 24/02/2022
| | Programming and testing | 4 weeks | 24/02/2022 | 24/03/2022
4 | 204108A | Studying more about components and design circuit. | 4 weeks | 10/01/2022 | 10/02/2021
| | Design PCB and compile the code | 2 weeks | 10/02/2022 | 24/02/2022
| | Programming and testing | 4 weeks | 24/02/2022 | 24/03/2022
5 | 204114M | Studying more about components and design circuit. | 4 weeks | 10/01/2022 | 10/02/2021
| | Design PCB and compile the code | 2 weeks | 10/02/2022 | 24/02/2022
| | Programming and testing | 4 weeks | 24/02/2022 | 24/03/2022

Table 2 - Action plan

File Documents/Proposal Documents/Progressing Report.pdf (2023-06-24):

## Faculty of Information Technology

## IN 1900-ICT Project

## Automatic Coconut breaking, scraping, and grinding machine

## Group No: 15

Nusky M.N.N. -204146L

Banu A.G.S. -204018X

Karunaweera R.L. -204096G

Kumarasingha H.J.A. -204108A

Lamahewage D.R. -204114M

Progress after the interim

After the interim these are the implementations in our project.

1. We add glass box to the machine for control the dust which comes at the time of coconut breaking.


2. Grinding system is automated by using another DC motor.

Glass box


Automated
Blender

3. We use color sensor to identify the scrap coconut and to control the coconut scaping time.
- Color sensor will identify the scraping time by detecting the color of the coconut shell and the white outer layer.


4. Using I2C Module for LCD display.

After the interim all our group members are studying basic micro controller programming and their individual components study through data sheets. We completed individual components code and simulation with proteus software. We are trying to complete full code for our system.

Color sensor

After the interim Individual Contribution to the Project

Name of student: Nusky M.N.N. (204146L)

1. Study basic microcontroller programming.
2. Studying LCD and Ultrasonic sensor module.
3. Programming LCD and Ultrasonic sensor module.
4. Study about microcontroller architecture and memory.

Name of student: Banu A.G.S. (204018X)

1. Study basic microcontroller programming.
2. Studying stepper motor module and power supply.
3. Programming stepper motor module.
4. Study about microcontroller architecture and memory.

Name of student: Karunaweera R.L. (204096G)

1. Study basic microcontroller programming.
2. Studying servo motor module and buzzer module.
3. Programming servo motor module and buzzer module.
4. Study about microcontroller architecture and memory.

Name of student: Kumarasingha H.J. A. (204108A)

1. Study basic microcontroller programming.
2. Studying DC motor module and color sensor.
3. Programming DC motor module and color sensor.
4. Study about microcontroller architecture and memory.

Name of student: Lamahewage D. R. (204114M)

1. Study basic microcontroller programming.
2. Studying IR sensor and Keypad modules.
3. Programming IR sensor and Keypad modules.

4.Study about microcontroller architecture and memory.

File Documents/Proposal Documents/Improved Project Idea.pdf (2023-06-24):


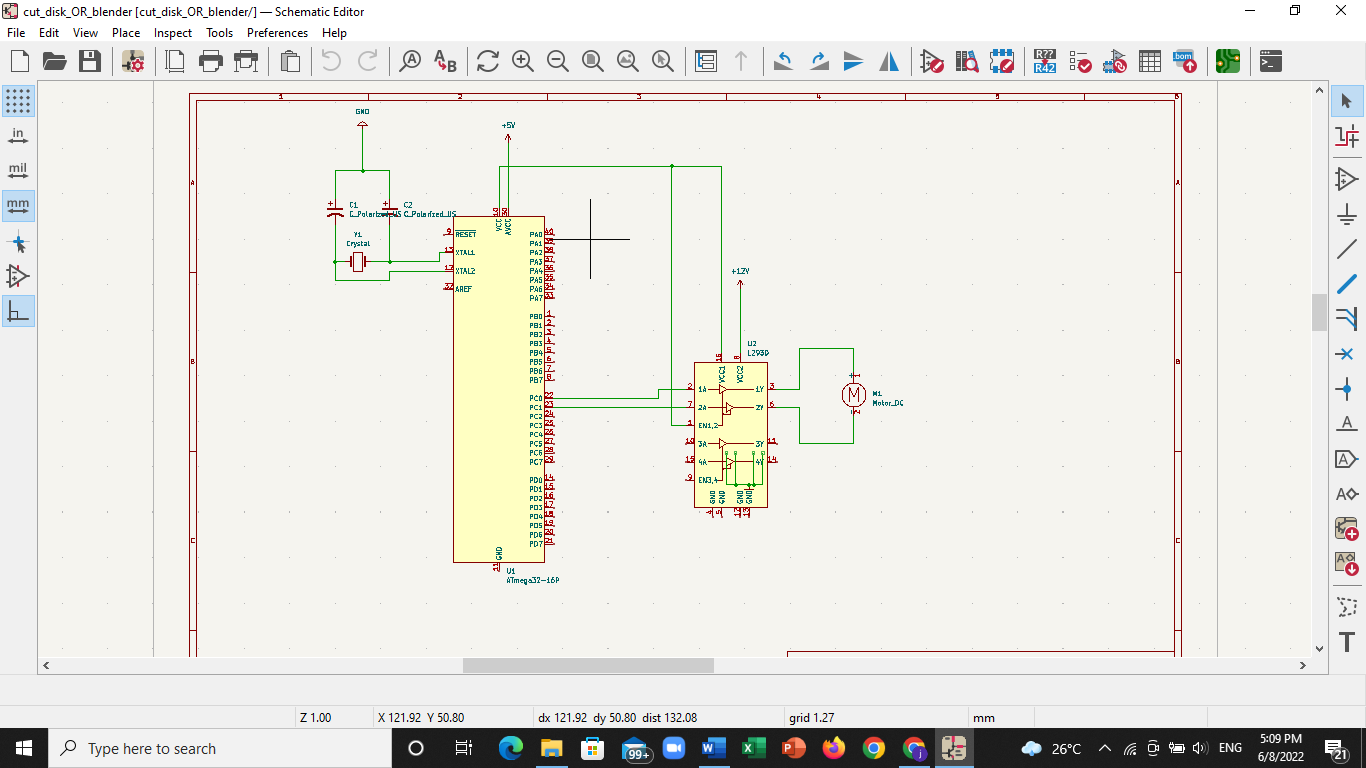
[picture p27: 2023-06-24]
Simulations/PCB Files/204108A-PCB Files/204108A-PCB Files/cut_disk_OR_blender/cut_disk_OR_blender_schematic_ss.PNG

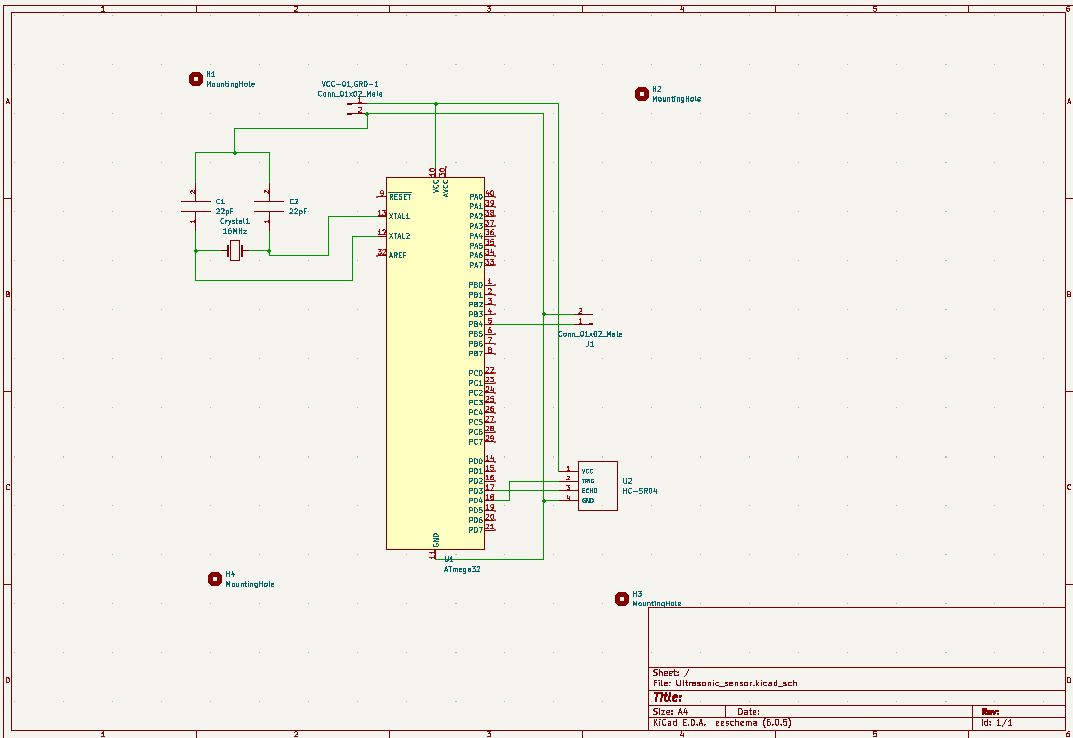
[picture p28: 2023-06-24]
Simulations/PCB Files/204146L-PCB Files/204146L-PCB Files/Ultarsonic_Sensor(204146L)/Ultrasonic schematic screenshot.png

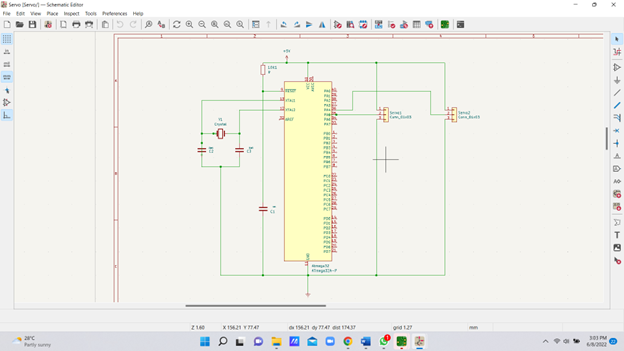
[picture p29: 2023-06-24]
Simulations/PCB Files/204096G-PCBs/204096G-PCBs'/PCB & Schematic Files-Servo/Schematic diagram-Screenshot.png

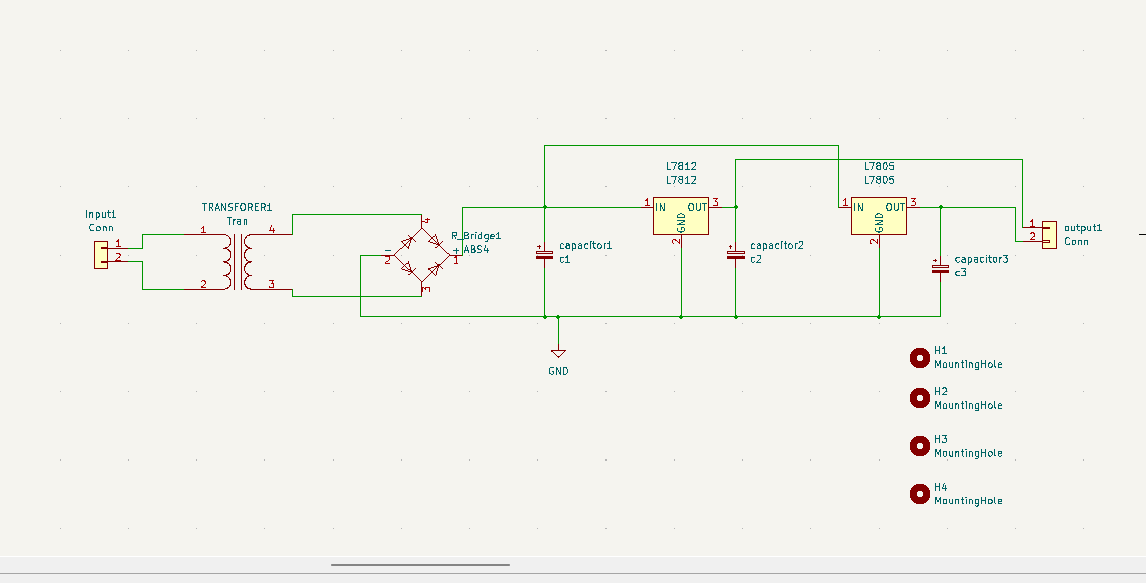
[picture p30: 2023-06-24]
Simulations/PCB Files/204018x-PCB Files/204018x-PCB Files/power_supply/powerSupply_schematic.png

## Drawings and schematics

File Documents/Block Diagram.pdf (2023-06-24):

## Faculty of Information Technology

## IN 1900-ICT Project

## Automatic Coconut breaking, scraping and grinding machine

Group No: 15

Nusky M.N.N. -204146L

Banu A.G.S. -204018X

Karunaweera R.L. -204096G

Kumarasingha H.J.A. -204108A

Lamahewage D.R. -204114M

Supervisor’s Name: BH Sudantha | Date of Submission: 08.06.2022

Dean/Senior lecturer

Dept. of Information Technology

Co-supervisor Name: Upulanka Premasiri

Lecturer

Dept. of Information Technology

Inputs | Process | Outputs

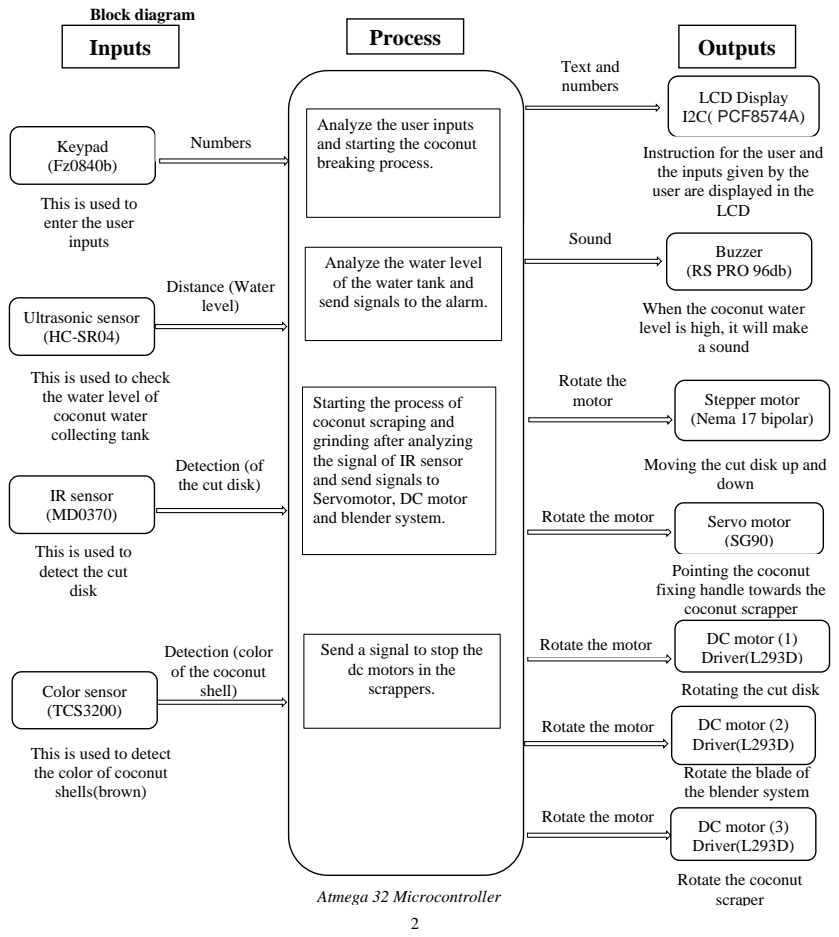
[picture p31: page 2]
Block diagram; Text and numbers; LCD Display; PCF8574A) Analyze the user inputs; Keypad (Fz0840b); Numbers; Buzzer (RS PRO 96db); Sound; Distance (Water level); Stepper motor (Nema 17 bipolar); Ultrasonic sensor (HC-SR04); Color sensor; scrappers.; (TCS3200); IR sensor; Servo motor; Atmega 32 Microcontroller; Rotate the motor; LCD; down; DC motor (1) Driver(L293D); DC motor (2); DC motor (3) Driver(L293D); a sound

and starting the coconut
breaking process.

Instruction for the user and
the inputs given by the
user are displayed in the

This is used to
enter the user
inputs

Analyze the water level
of the water tank and
send signals to the alarm.

When the coconut water
level is high, it will make

This is used to check
the water level of
coconut water
collecting tank

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

Detection (of
the cut disk)

Moving the cut disk up and

Rotate the motor

detect the cut
disk

Pointing the coconut
fixing handle towards the
coconut scrapper

Detection (color
of the coconut
shell)

Send a signal to stop the
dc motors in the

Rotating the cut disk

Driver(L293D) This is used to detect
the color of coconut
shells(brown)

Rotate the blade of
the blender system

Rotate the coconut
scraper

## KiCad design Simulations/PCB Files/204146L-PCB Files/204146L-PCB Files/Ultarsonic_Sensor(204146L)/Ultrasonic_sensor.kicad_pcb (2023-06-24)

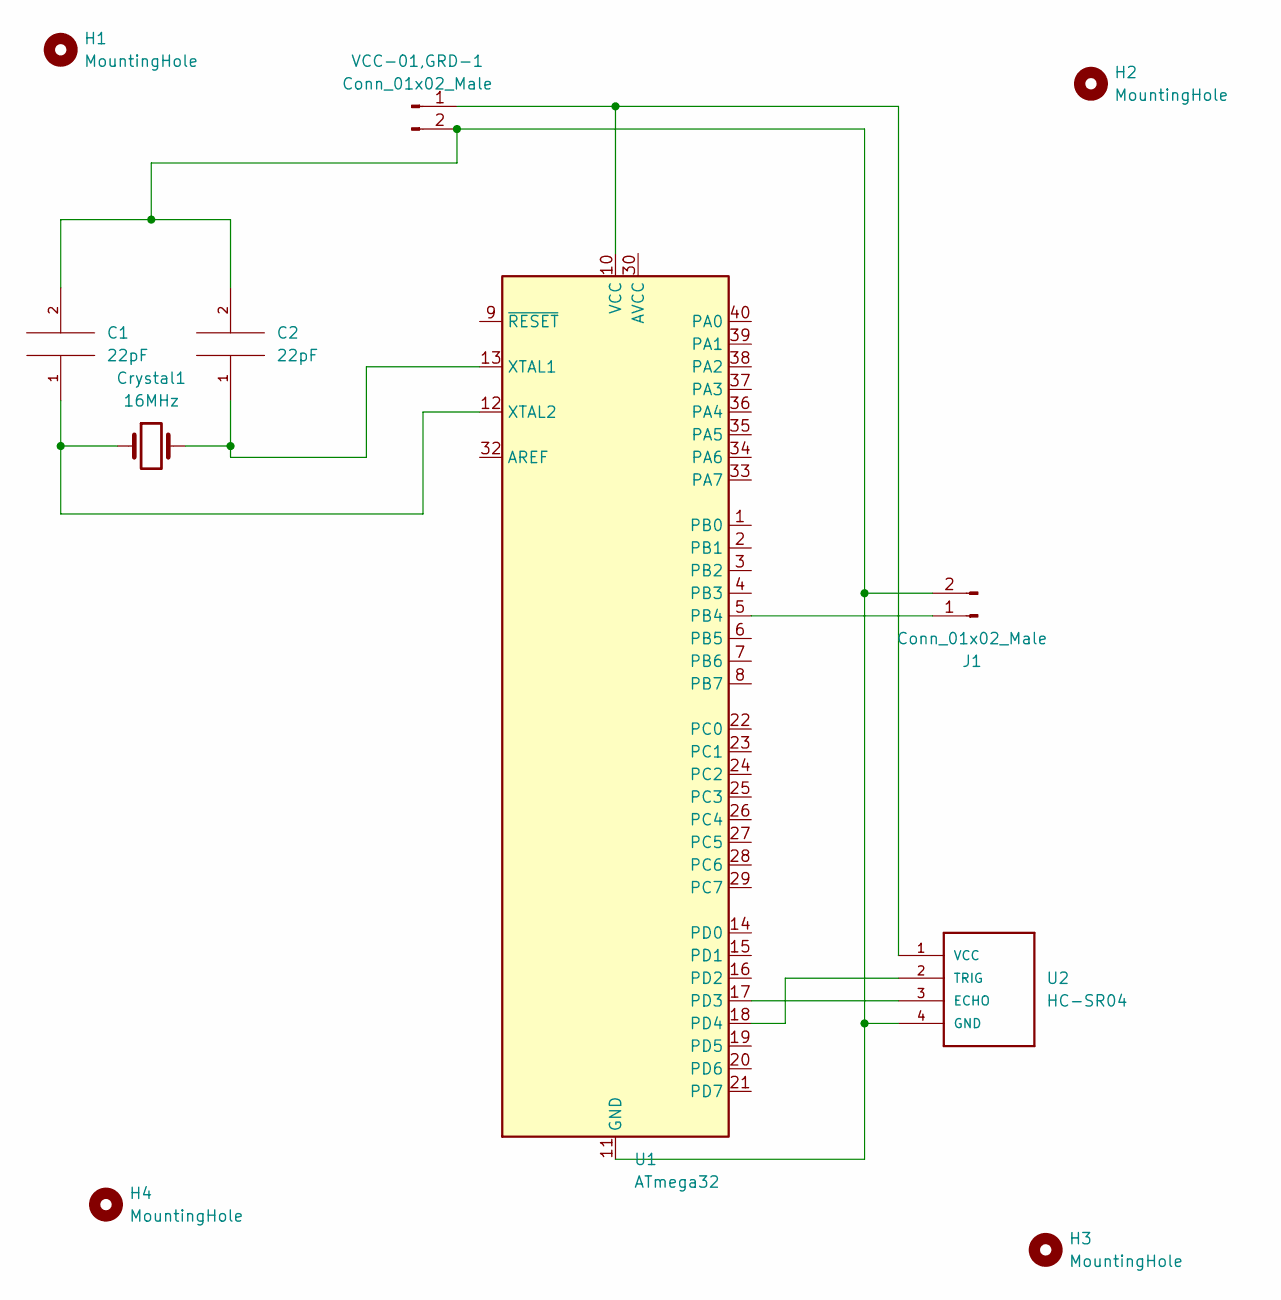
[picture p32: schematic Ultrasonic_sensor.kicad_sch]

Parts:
C1, C2: 22pF; CP_Axial_L10.0mm_D4.5mm_P15.00mm_Horizontal
Crystal1: 16MHz; Crystal_AT310_D3.0mm_L10.0mm_Horizontal
H1, H2, H3, H4: MountingHole; MountingHole_2.5mm
J1: Conn_01x02_Male; PinHeader_1x02_P1.00mm_Horizontal
U1: ATmega32; DIP-40_W15.24mm
U2: HC-SR04; PinHeader_1x04_P2.54mm_Horizontal
VCC-01,GRD-1: Conn_01x02_Male; PinHeader_1x02_P2.00mm_Horizontal

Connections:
unnamed: C1.1, Crystal1.1, U1.12 (XTAL2)
unnamed 1: C1.2, C2.2, J1.2, U1.11 (GND), U1.31 (GND), U2.4 (GND), VCC-01,GRD-1.2; also elsewhere on the board
unnamed: C2.1, Crystal1.2, U1.13 (XTAL1)
unnamed: J1.1, U1.5 (PB4)
unnamed 4: U1.10 (VCC), U2.1 (VCC), VCC-01,GRD-1.1; also elsewhere on the board
unnamed: U1.17 (PD3), U2.3 (ECHO)
unnamed: U1.18 (PD4), U2.2 (TRIG)

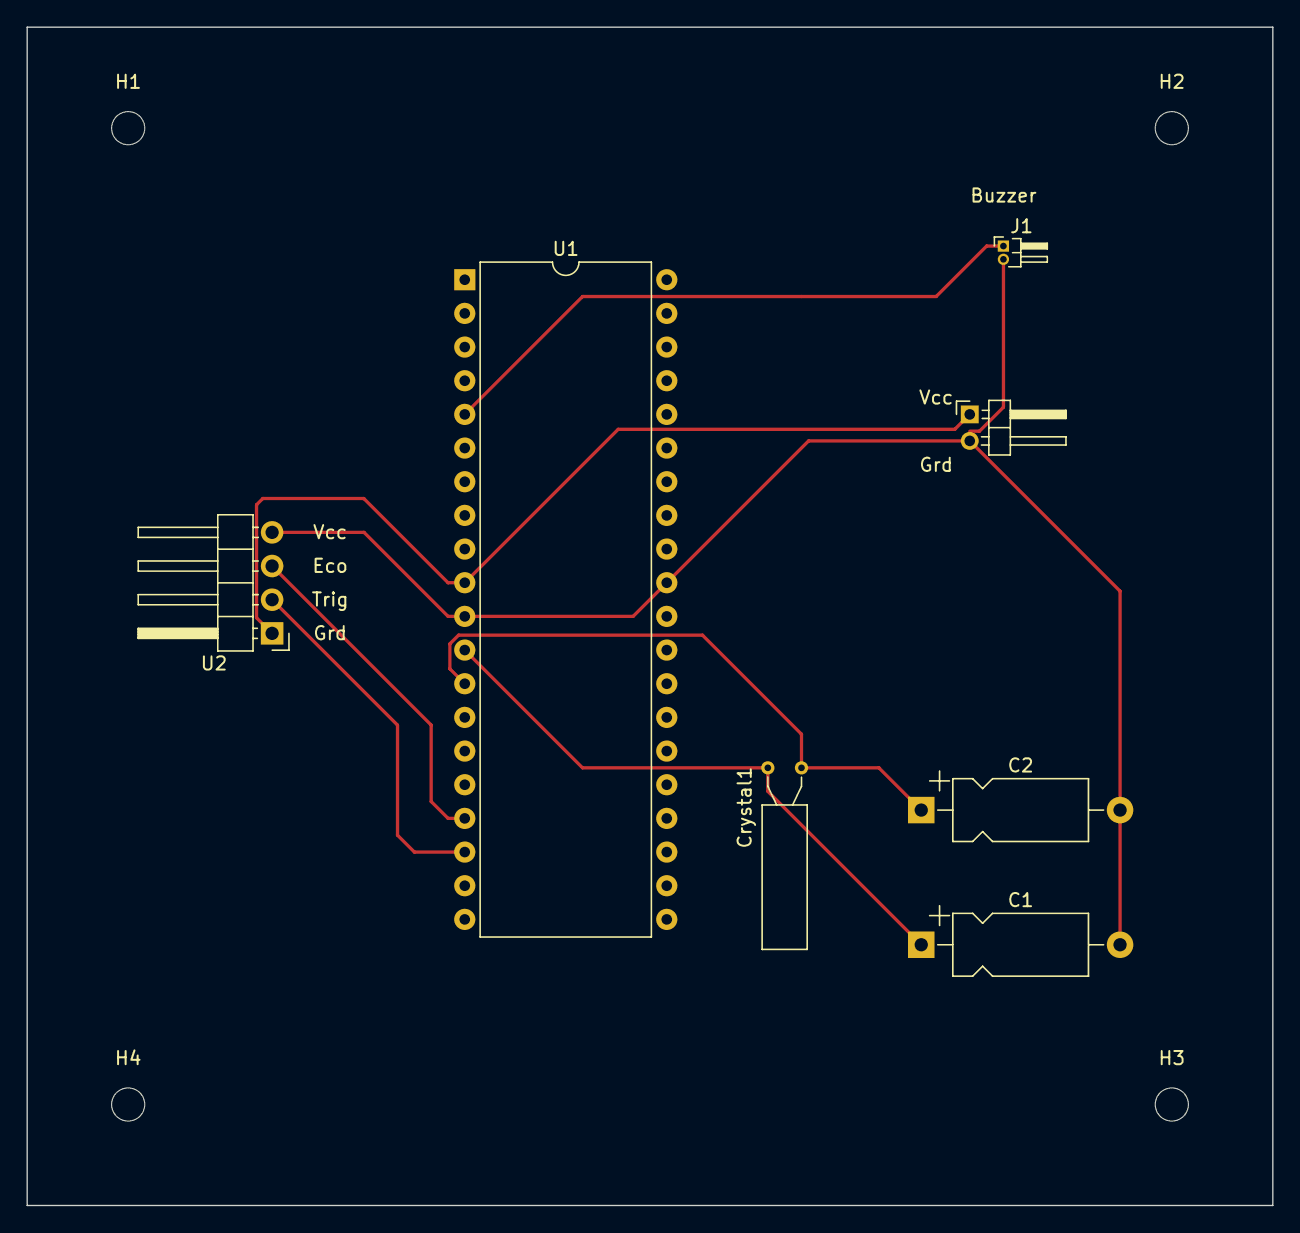
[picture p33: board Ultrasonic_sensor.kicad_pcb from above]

Board: 2 copper layers, 94.0 x 88.9 mm, 11 parts (0 on the bottom side), 7 nets.

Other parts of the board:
Vcc,Grd: Conn_01x02_Male; PinHeader_1x02_P2.00mm_Horizontal

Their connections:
unnamed 1: Vcc,Grd.2; also elsewhere on the board
unnamed 4: Vcc,Grd.1; also elsewhere on the board

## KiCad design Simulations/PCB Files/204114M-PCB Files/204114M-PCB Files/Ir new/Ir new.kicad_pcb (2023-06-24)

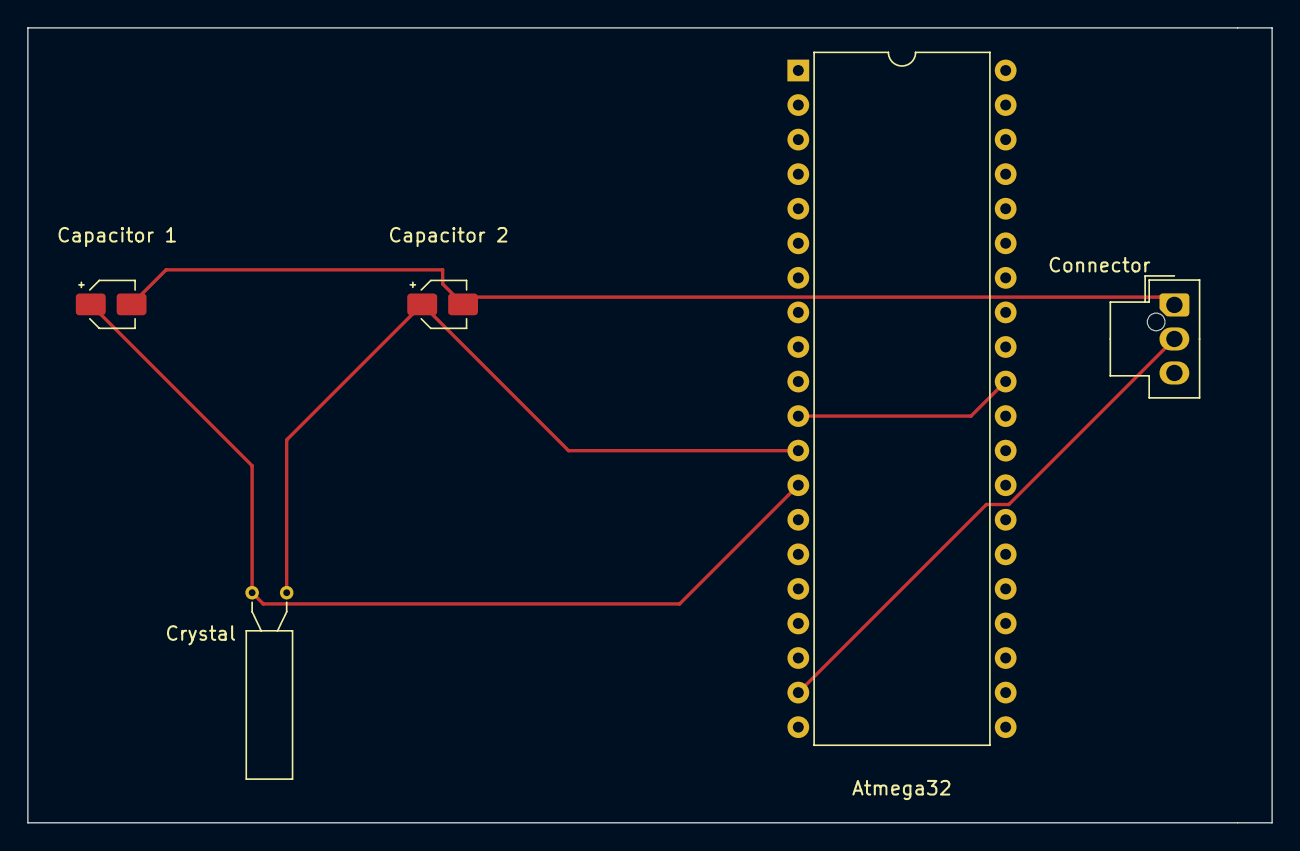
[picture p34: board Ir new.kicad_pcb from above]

Board: 2 copper layers, 91.4 x 58.4 mm, 5 parts (0 on the bottom side), 5 nets.

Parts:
Atmega32: ATmega32-16P; DIP-40_W15.24mm
Capacitor 1, Capacitor 2: CAP; CP_Elec_3x5.4
Connector: Conn_01x03_Female; Molex_Nano-Fit_105309-xx03_1x03_P2.50mm_Vertical
Crystal: Crystal; Crystal_AT310_D3.0mm_L10.0mm_Horizontal

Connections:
GND: Capacitor 1.2, Capacitor 2.2, Connector.1
unnamed: Atmega32.13 (XTAL1), Capacitor 1.1, Crystal.1
unnamed: Atmega32.12 (XTAL2), Capacitor 2.1, Crystal.2
unnamed: Atmega32.19 (PD5), Connector.2
unnamed: Atmega32.11 (GND), Atmega32.31 (GND)

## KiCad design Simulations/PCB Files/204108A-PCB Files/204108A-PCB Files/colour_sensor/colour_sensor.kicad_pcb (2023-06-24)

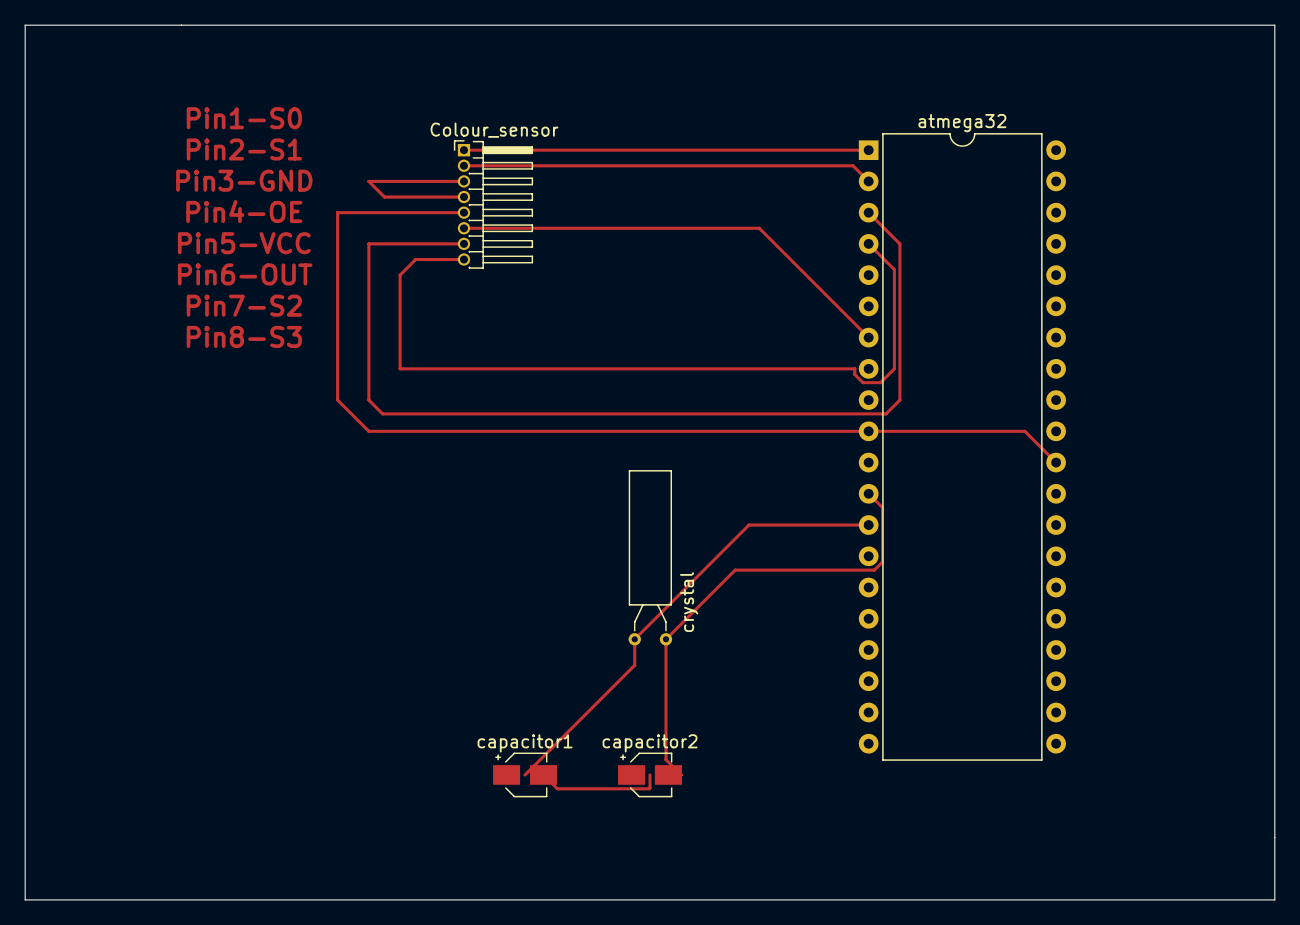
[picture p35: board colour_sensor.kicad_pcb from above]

Board: 2 copper layers, 101.6 x 71.1 mm, 5 parts (0 on the bottom side), 11 nets.

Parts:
Colour_sensor: TCS3200D-TR; PinHeader_1x08_P1.27mm_Horizontal
atmega32: ATmega32-16P; DIP-40_W15.24mm
capacitor1, capacitor2: C_Polarized_US; CP_Elec_3x5.3
crystal: Crystal; Crystal_AT310_D3.0mm_L10.0mm_Horizontal

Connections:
+5V: Colour_sensor.VCC (VDD), atmega32.10 (VCC), atmega32.30 (AVCC)
Earth: Colour_sensor.GND (~OE), Colour_sensor.OE (GND)
GND: capacitor1.1, capacitor2.1
unnamed: atmega32.12 (XTAL2), capacitor2.2, crystal.1
unnamed: atmega32.13 (XTAL1), capacitor1.2, crystal.2
unnamed: Colour_sensor.S0, atmega32.1 (PB0)
unnamed: Colour_sensor.S1, atmega32.2 (PB1)
unnamed: Colour_sensor.OUT, atmega32.7 (PB6)
unnamed: Colour_sensor.S2, atmega32.3 (PB2)
unnamed: Colour_sensor.S3, atmega32.4 (PB3)
unnamed: atmega32.11 (GND), atmega32.31 (GND)

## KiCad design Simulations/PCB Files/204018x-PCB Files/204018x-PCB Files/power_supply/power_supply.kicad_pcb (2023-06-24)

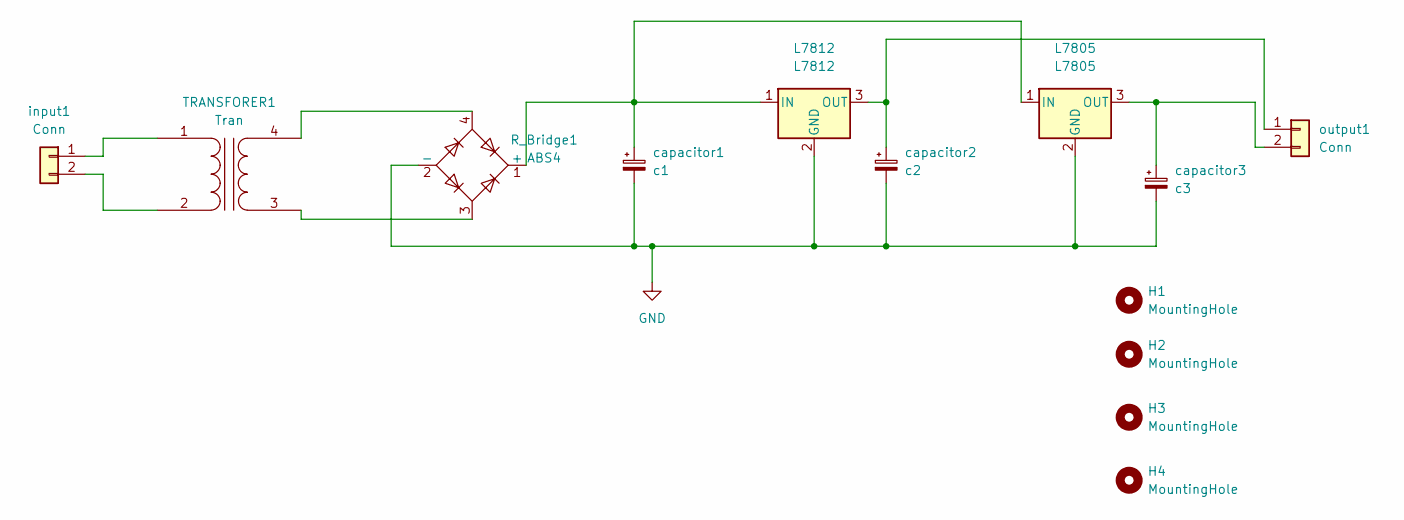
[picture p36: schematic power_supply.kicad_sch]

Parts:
H1: MountingHole; MountingHole_2.1mm
H2, H3, H4: MountingHole
L7805: L7805; TO-220-3_Horizontal_TabDown
L7812: L7812; TO-220-3_Horizontal_TabDown
R_Bridge1: ABS4; Diode_Bridge_Diotec_ABS
TRANSFORER1: Tran; PinHeader_1x04_P2.54mm_Vertical
capacitor1: c1; CP_Elec_3x5.4
capacitor2: c2; CP_Elec_4x3
capacitor3: c3; CP_Elec_4x3
input1: Conn; PinSocket_1x02_P1.00mm_Vertical
output1: Conn; PinSocket_1x02_P1.00mm_Vertical

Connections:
GND: L7805.2 (GND), L7812.2 (GND), R_Bridge1.2 (-), capacitor1.2, capacitor2.2, capacitor3.2
unnamed: L7805.1 (IN), L7812.1 (IN), R_Bridge1.1 (+), capacitor1.1
unnamed: L7805.3 (OUT), capacitor3.1, output1.2
unnamed: L7812.3 (OUT), capacitor2.1, output1.1
unnamed: R_Bridge1.3, TRANSFORER1.3 (SA)
unnamed: R_Bridge1.4, TRANSFORER1.4 (SB)
unnamed: TRANSFORER1.1 (AA), input1.1
unnamed: TRANSFORER1.2 (AB), input1.2

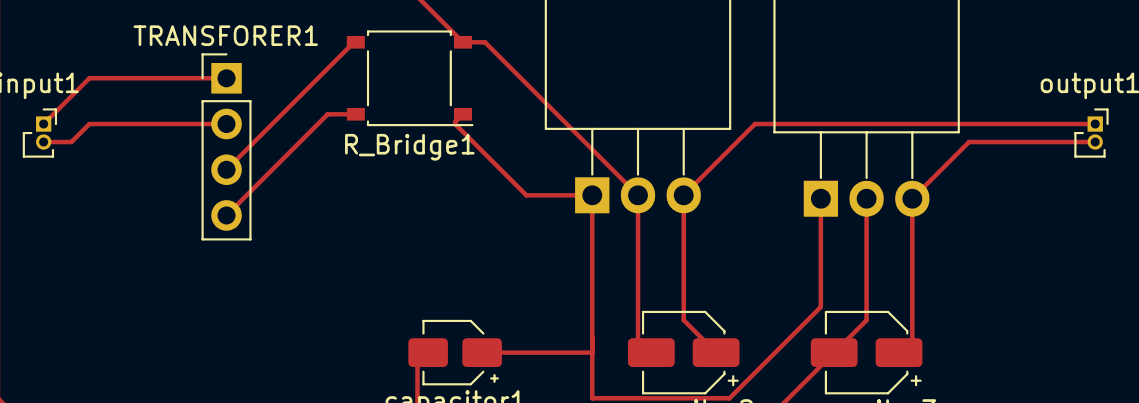
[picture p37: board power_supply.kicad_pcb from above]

Board: 2 copper layers, 13 parts (0 on the bottom side), 8 nets.

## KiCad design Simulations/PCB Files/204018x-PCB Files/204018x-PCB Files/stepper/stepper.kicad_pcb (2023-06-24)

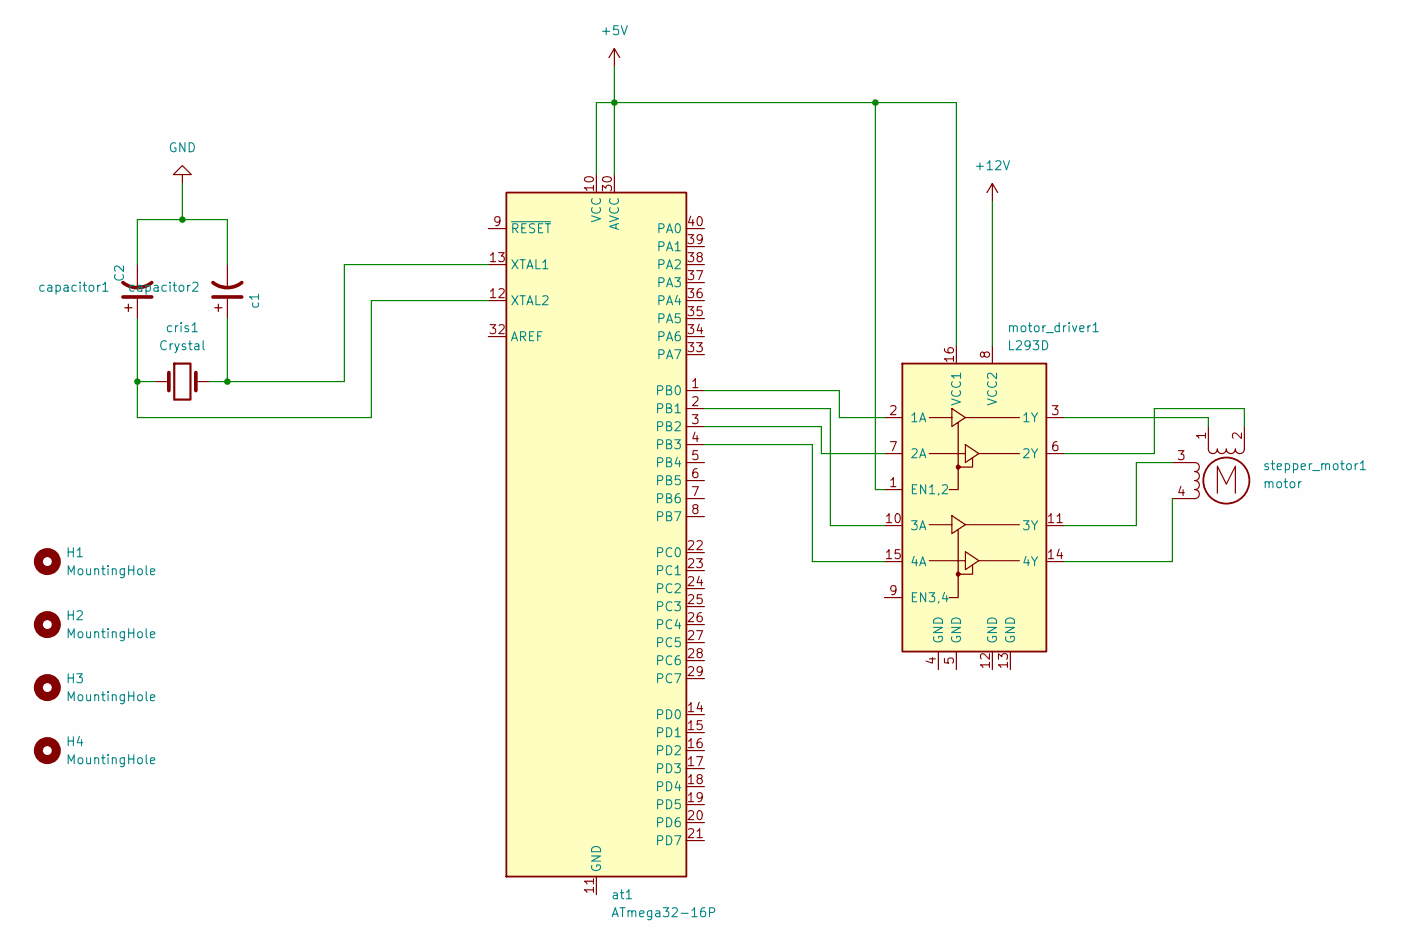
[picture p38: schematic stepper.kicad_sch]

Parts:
H1, H2, H3, H4: MountingHole; MountingHole_2.1mm
at1: ATmega32-16P; DIP-40_W15.24mm
capacitor1: C2; CP_Elec_3x5.3
capacitor2: c1; CP_Elec_3x5.3
cris1: Crystal; Crystal_AT310_D3.0mm_L10.0mm_Horizontal
motor_driver1: L293D; DIP-16_W7.62mm
stepper_motor1: motor; PinHeader_1x04_P1.27mm_Horizontal

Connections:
+5V: at1.10 (VCC), at1.30 (AVCC), motor_driver1.1 (EN1,2), motor_driver1.16 (VCC1)
+12V: motor_driver1.8 (VCC2)
GND: capacitor1.2, capacitor2.2
unnamed: at1.1 (PB0), motor_driver1.2 (1A)
unnamed: at1.2 (PB1), motor_driver1.10 (3A)
unnamed: at1.3 (PB2), motor_driver1.7 (2A)
unnamed: at1.4 (PB3), motor_driver1.15 (4A)
unnamed: at1.11 (GND), at1.31 (GND)
unnamed: at1.12 (XTAL2), capacitor1.1, cris1.1
unnamed: at1.13 (XTAL1), capacitor2.1, cris1.2
unnamed: motor_driver1.3 (1Y), stepper_motor1.1
unnamed: motor_driver1.6 (2Y), stepper_motor1.2 (-)
unnamed: motor_driver1.11 (3Y), stepper_motor1.3
unnamed: motor_driver1.14 (4Y), stepper_motor1.4

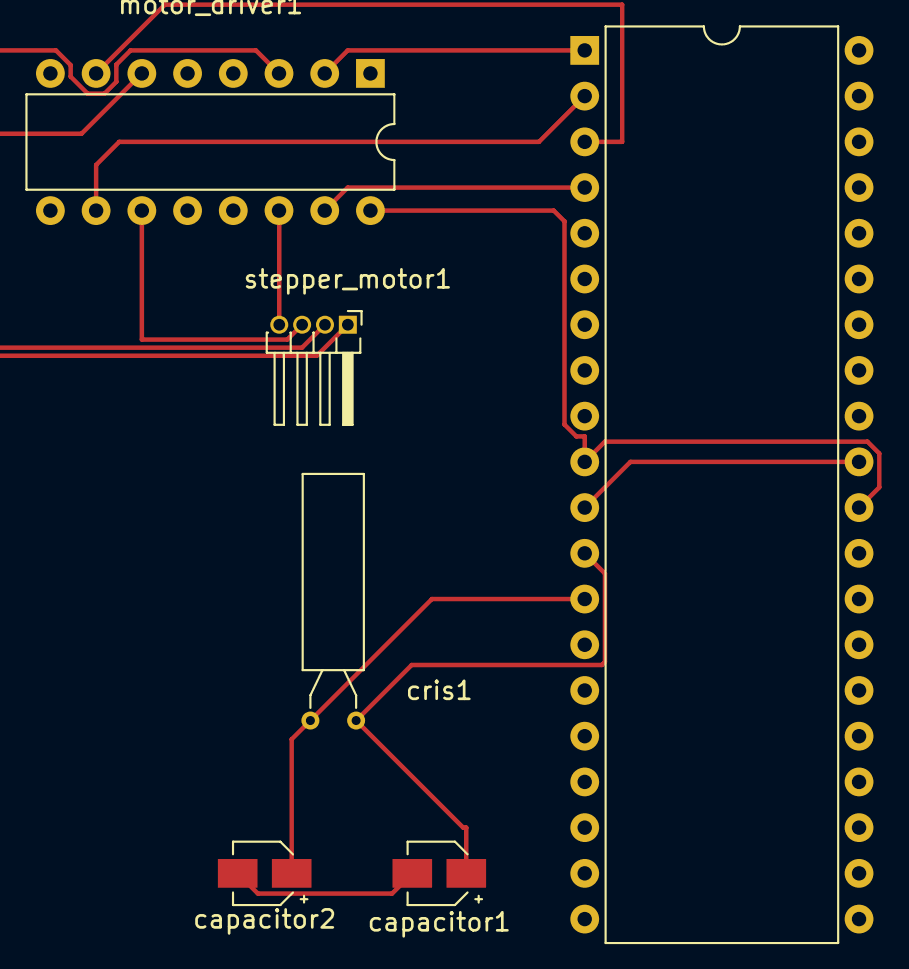
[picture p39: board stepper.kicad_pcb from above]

Board: 2 copper layers, 10 parts (0 on the bottom side), 13 nets.

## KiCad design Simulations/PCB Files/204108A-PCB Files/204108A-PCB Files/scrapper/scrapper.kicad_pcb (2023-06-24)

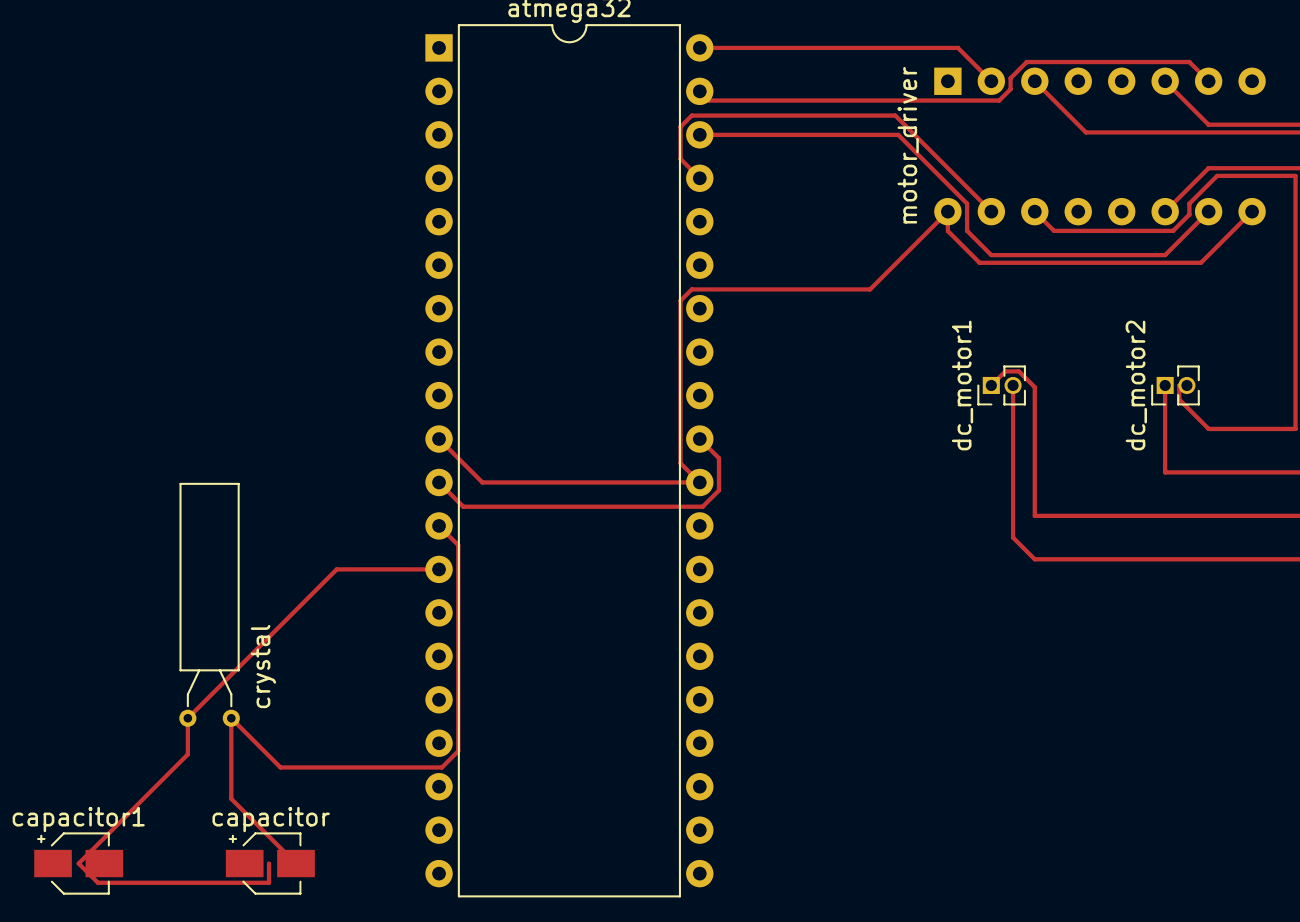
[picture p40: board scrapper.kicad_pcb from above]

Board: 2 copper layers, 7 parts (1 on the bottom side), 13 nets.

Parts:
atmega32: ATmega32-16P; DIP-40_W15.24mm
capacitor, capacitor1: C_Polarized_US; CP_Elec_3x5.3
crystal: Crystal; Crystal_AT310_D3.0mm_L10.0mm_Horizontal
dc_motor1, dc_motor2: Motor_DC; PinHeader_1x02_P1.27mm_Vertical
motor_driver: L293D; DIP-16_W7.62mm

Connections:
+5V: atmega32.10 (VCC), atmega32.30 (AVCC), motor_driver.1 (EN1,2), motor_driver.9 (EN3,4), motor_driver.16 (VCC1)
GND: capacitor.1, capacitor1.1
unnamed: atmega32.12 (XTAL2), capacitor.2, crystal.1
unnamed: atmega32.13 (XTAL1), capacitor1.2, crystal.2
unnamed: dc_motor1.1 (+), motor_driver.3 (1Y)
unnamed: dc_motor1.2 (-), motor_driver.6 (2Y)
unnamed: dc_motor2.1 (+), motor_driver.11 (3Y)
unnamed: dc_motor2.2 (-), motor_driver.14 (4Y)
unnamed: atmega32.11 (GND), atmega32.31 (GND)
unnamed: atmega32.37 (PA3), motor_driver.15 (4A)
unnamed: atmega32.38 (PA2), motor_driver.10 (3A)
unnamed: atmega32.39 (PA1), motor_driver.7 (2A)
unnamed: atmega32.40 (PA0), motor_driver.2 (1A)

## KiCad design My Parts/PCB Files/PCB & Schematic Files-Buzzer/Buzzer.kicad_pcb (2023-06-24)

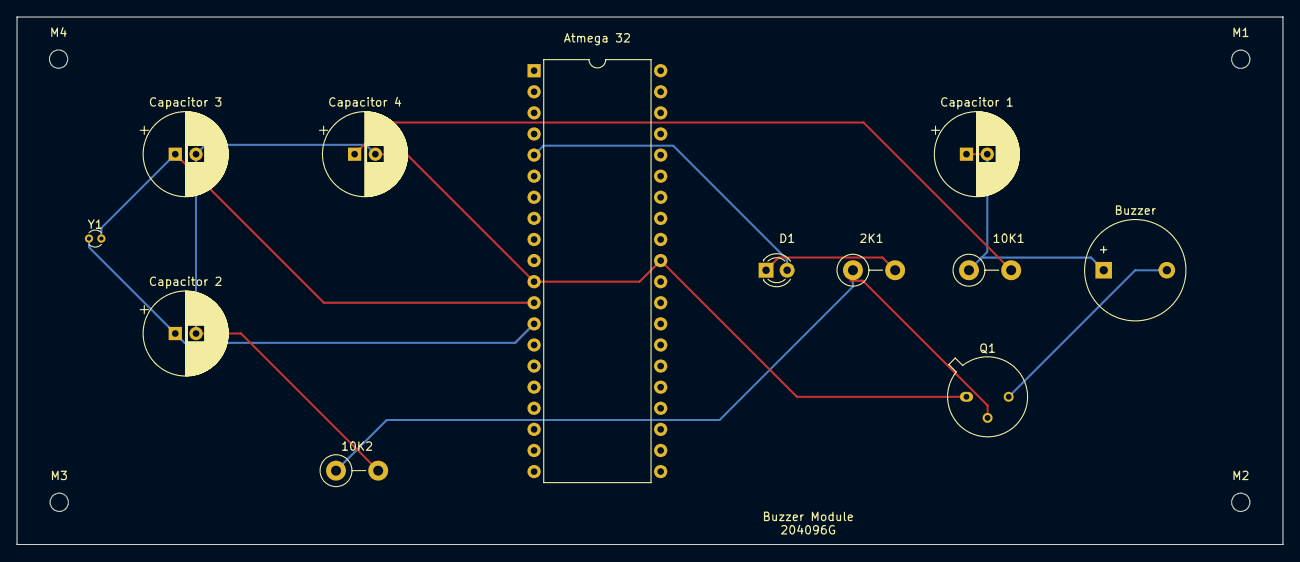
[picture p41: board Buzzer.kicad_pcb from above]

Board: 2 copper layers, 152.4 x 63.5 mm, 16 parts (0 on the bottom side), 9 nets.

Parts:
2K1: Resistor 1; R_Axial_DIN0411_L9.9mm_D3.6mm_P5.08mm_Vertical
10K1: Resistor 2; R_Axial_DIN0411_L9.9mm_D3.6mm_P5.08mm_Vertical
10K2: Resistor 3; R_Axial_DIN0411_L9.9mm_D3.6mm_P5.08mm_Vertical
Atmega 32: ATmega32A-P; DIP-40_W15.24mm
Buzzer: Buzzer; Buzzer_12x9.5RM7.6
Capacitor 1: 4.7uF; CP_Radial_D10.0mm_P2.50mm
Capacitor 2, Capacitor 3: 22pF; CP_Radial_D10.0mm_P2.50mm
Capacitor 4: 1uF; CP_Radial_D10.0mm_P2.50mm
D1: LED; LED_D3.0mm
M1, M2, M3, M4: MountingHole_2.2mm_M2
Q1: NPN Transistor; TO-39-3
Y1: Crystal; Crystal_DS10_D1.0mm_L4.3mm_Vertical

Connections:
+6V: 10K1.1, Buzzer.1 (-), Capacitor 1.1, Capacitor 1.2
Earth: 10K2.2, Atmega 32.11 (GND), Atmega 32.31 (GND), Capacitor 2.2, Capacitor 3.2, Capacitor 4.2, Q1.1 (E)
unnamed: 10K1.2, Capacitor 4.1
unnamed: 2K1.1, 10K2.1, Q1.2 (B)
unnamed: 2K1.2, D1.1 (K)
unnamed: Atmega 32.13 (XTAL1), Capacitor 2.1, Y1.1
unnamed: Atmega 32.12 (XTAL2), Capacitor 3.1, Y1.2
unnamed: Buzzer.2 (+), Q1.3 (C)
unnamed: Atmega 32.5 (PB4), D1.2 (A)

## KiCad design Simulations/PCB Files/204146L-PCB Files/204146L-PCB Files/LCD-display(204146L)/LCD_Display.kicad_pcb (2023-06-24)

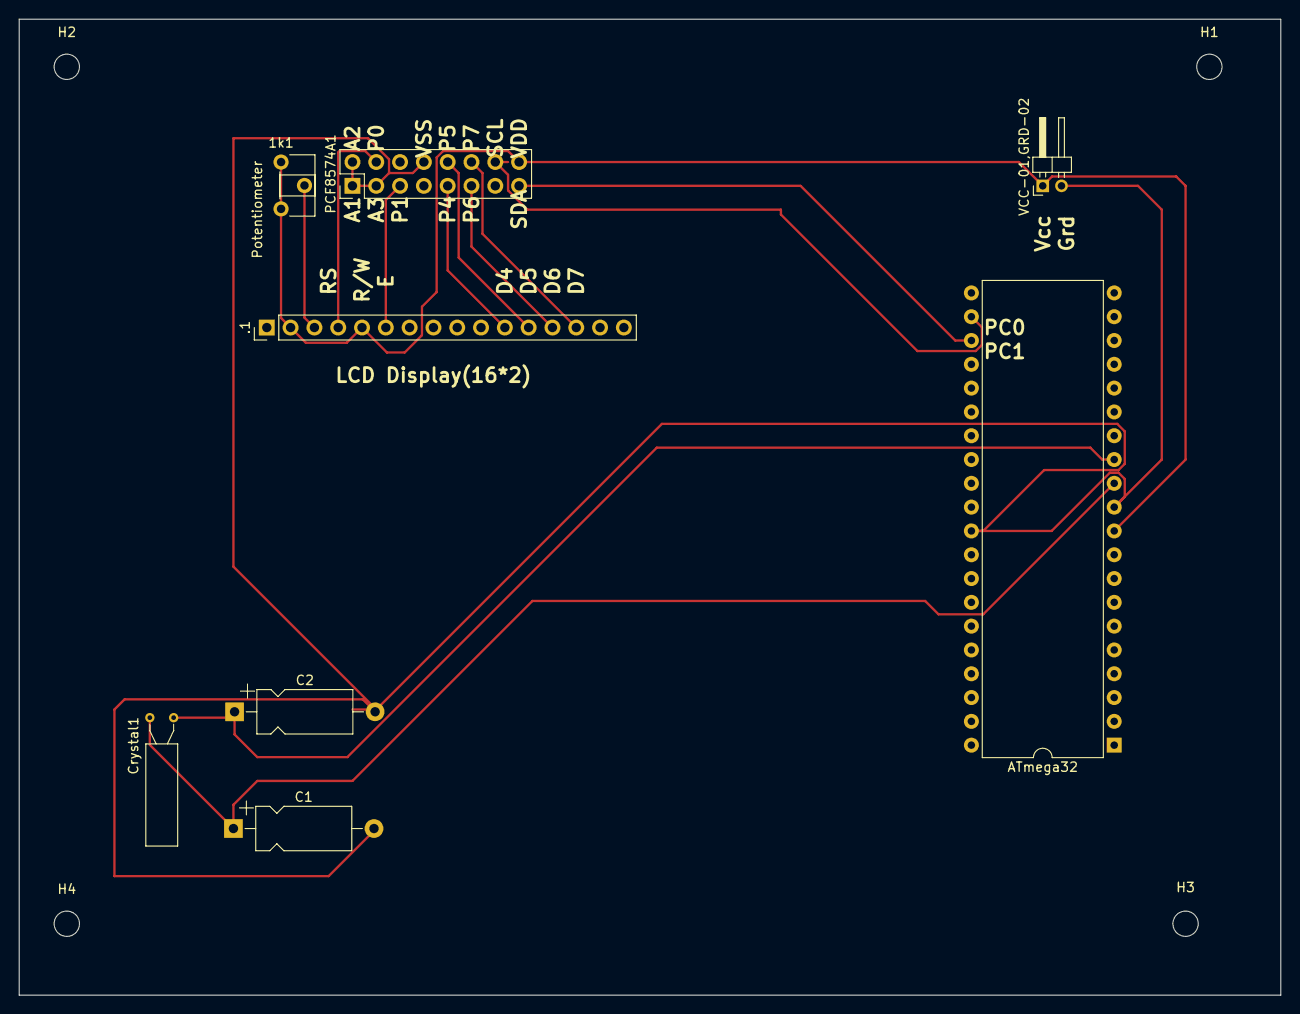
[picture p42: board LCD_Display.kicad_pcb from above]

Board: 2 copper layers, 134.6 x 104.1 mm, 12 parts (0 on the bottom side), 5 nets.

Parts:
1k1: Potentiometer; Potentiometer_ACP_CA6-H2,5_Horizontal
.1: 16*2 LCD; PinHeader_1x16_P2.54mm_Vertical
ATmega32: ATmega32; DIP-40_W15.24mm
C1, C2: 22pF; CP_Axial_L10.0mm_D4.5mm_P15.00mm_Horizontal
Crystal1: 16MHz; Crystal_AT310_D3.0mm_L10.0mm_Horizontal
H1, H2, H3, H4: MountingHole; MountingHole_2.7mm
PCF8574A1: .; PinHeader_2x08_P2.54mm_Vertical
VCC-01,GRD-02: Conn_01x02_Male; PinHeader_1x02_P2.00mm_Horizontal

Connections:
unnamed: 1k1.1, 1k1.3, .1.2 (VDD), .1.5 (R/W), ATmega32.PIN 10 (VCC), PCF8574A1.16 (VDD), VCC-01,GRD-02.1
unnamed: ATmega32.12 (XTAL2), C1.1, Crystal1.1
unnamed: ATmega32.11 (GND), ATmega32.31 (GND), C1.2, C2.2, PCF8574A1.1 (A0), PCF8574A1.2 (A1), PCF8574A1.3 (A2), PCF8574A1.8 (VSS), VCC-01,GRD-02.2
unnamed: ATmega32.13 (XTAL1), C2.1, Crystal1.2
unnamed: ATmega32.23 (PC1), PCF8574A1.15 (SDA)

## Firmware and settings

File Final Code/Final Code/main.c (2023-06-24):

#define F_CPU 8000000UL
#include <avr/io.h>
#include <util/delay.h>
#include <avr/interrupt.h>

#define LCD PORTC
#define EN 6
#define RS 0
#define RW 1
#define brown PORTD & (1<<7)
#define ir PIND & (1<<5)
unsigned char keypad();
void i2c_init();
void i2c_start();
void i2c_write(char x);
char i2c_read();
void HCSR04();
void uart_transmit (unsigned char data);
void anticlockstepper();
void clockstepper();
void servo1();
void servo2();
void DC1();
void DC2();
void DC3time();

int main(void){
	i2c_init();
	i2c_start();
	i2c_write(0x70);
	lcd_init();
	unsigned char x;
	// make PA0 to PA3 = output and PA4 to PA7 = Input
	DDRC |=0X0f; //DC MOTOR CUTDISK
	DDRC |= 0XF0; //making keypad row pin as output
	DDRB = 0XFF;//making stepper pin output
	DDRD &= ~(1<<0) ;
	DDRD &= ~(1<<1) ;
	DDRD &= ~(1<<2) ; // keypad coloumn pin as input
	DDRD &= ~(1<<5) ;// IR AS INPUT
	DDRD &= ~(1<<6) ;// white AS INPUT
	DDRD &= ~(1<<7) ;// brown AS INPUT
	DDRA = 0XFF;

	
	//while(1){
		PORTC &=~ 0xf0 ; //PIN4-7 of port c is low
		PORTD |= ( 1<<0) ; //PIN0 of port D is high
		PORTD |= ( 1<<1) ;
		PORTD |= ( 1<<2) ;
		
		//ir detect
			
		if(ir)
		{
			
			cutdiskstop();
			anticlockstepper();
			lcd_cmd(0x01);
			lcd_msg("scrap or not");
			_delay_ms(200);
			lcd_cmd(0xC0);
			lcd_msg("yes-1 | No-2");
			_delay_ms(600);
			lcd_cmd(0xC0);
			lcd_cmd(0x01);
			x=keypad();
			lcd_dwr(x);
			_delay_ms(300);
			
			if(x =='1')
			{
				lcd_cmd(0x01);
				lcd_msg("How many parts?");
				_delay_ms(300);
				lcd_cmd(0xC0);
				lcd_msg("One-1 | Two-2");
				_delay_ms(1000);
				lcd_cmd(0xC0);
				lcd_cmd(0x01);
				x=keypad();
				lcd_dwr(x);
				_delay_ms(500);
				lcd_cmd(0x01);
				if(x =='1')
				{
					servo1();
					_delay_ms(1000);
					DC1();//ONLY 1 dc rotate
					_delay_ms(1000);
					
					//if(PORTD |= 0x80)
					//{
						if(PORTD = PORTD | 1 << PD6){
						stopDC(); //DC1 OFF
						lcd_msg("-scraping done!-");
						_delay_ms(1000);
						lcd_cmd(0x01);
						lcd_msg("-Grind or not?-");
						lcd_cmd(0xC0);
						_delay_ms(300);
						lcd_msg("YES-1 | NO-2");
						_delay_ms(700);
						lcd_cmd(0xC0);
						lcd_cmd(0x01);
						x=keypad();
						lcd_dwr(x);
						_delay_ms(500);
						//KEYPAD
						
						if(x=='1')
						{
							//INPUT time
							lcd_cmd(0x01);
							lcd_msg("Time in min");
							_delay_ms(1000);
							lcd_cmd(0xC0);
							lcd_cmd(0x01);
							x=keypad();
							lcd_dwr(x);
							_delay_ms(500);
							DC3time();//grind
							
							//PORTB = PORTB | 1 << PB4;//buzzer will on
							lcd_cmd(0x01);
							HCSR04();
							_delay_ms(1000);
						}
						else if(x=='2')
						{
							//PORTB = PORTB | 1 << PB4;//buzzer will on
							lcd_cmd(0x01);
							HCSR04();
							_delay_ms(1000);
							//machine off
						}
					}
				}
				
				
				else if(x == '2')
				{
					
					servo2();
					_delay_ms(1000);
					DC2();
					_delay_ms(1000);
					
					if(PORTD |= 0x80)
					{
						stopDC();
						_delay_ms(500); //DC1 OFF
						lcd_msg("-scraping done!-");
						_delay_ms(1000);
						lcd_cmd(0x01);
						lcd_msg("-Grind or not?-");
						lcd_cmd(0xC0);
						_delay_ms(300);
						lcd_msg("YES-1 | NO-2");
						_delay_ms(1000);
						lcd_cmd(0xC0);
						lcd_cmd(0x01);
						x=keypad();
						lcd_dwr(x);
						_delay_ms(300);
						//KEYPAD
						if(x =='1')
						{
							//INPUT time
							lcd_cmd(0x01);
							lcd_msg("Time in min");
							_delay_ms(1000);
							lcd_cmd(0xC0);
							lcd_cmd(0x01);
							x=keypad();
							lcd_dwr(x);
							
							_delay_ms(300);
							DC3time();//grind
							_delay_ms(300);
							
							//PORTB = PORTB | 1 << PB4;//buzzer will on
							lcd_cmd(0x01);
							HCSR04();
							_delay_ms(1000);
							//machine off
						}
						if(x=='2')
						{
							//PORTB = PORTB | 1 << PB4;//buzzer will on
							HCSR04();
							_delay_ms(1000);
							//machine off
						}
					}
				}
			}
			else if(x=='2')
			{
				//PORTB = PORTB | 1 << PB4;//buzzer will on
				HCSR04();
				/*_delay_ms(1000);
				lcd_cmd(0x01);
				lcd_msg("---THANK YOU---");
				_delay_ms(1200);
				lcd_cmd(0x01);*/
			}
			
			
		}
		else{
			lcd_cmd(0x80);
			lcd_msg("----Welcome----");
			_delay_ms(500);
			lcd_cmd(0x01);
			lcd_msg("---Group-15---");
			_delay_ms(500);
			lcd_cmd(0xC0);
			lcd_msg("--COCO MASTER--");
			_delay_ms(1000);
			lcd_cmd(0x01);
			
			//stepper rotate clockwise
			cutdisk();
			clockstepper();
		}
	
	//}
	return 0;
}

//stepper motor
void clockstepper()
{    do
	{
		PORTB = 0B00001000;
		_delay_ms(50);
		PORTB = 0B00000100;
		_delay_ms(50);
		PORTB = 0B00000010;
		_delay_ms(50);
		PORTB = 0B00000001;
		_delay_ms(50);
	}while(!ir);
}

void anticlockstepper()
{
	
		PORTB = 0B00000001;
		_delay_ms(50);
		PORTB = 0B00000010;
		_delay_ms(50);
		PORTB = 0B00000100;
		_delay_ms(50);
		PORTB = 0B00001000;
		_delay_ms(50);
	
	
}

void cutdisk()
{
	do
	{
		PORTC |= (1<<3);
	} while (!ir);
	
}
void cutdiskstop()
{
	PORTC &=~ (0x0C);
}
void lcd_Print (char*str){
	int i;
	for(i=0;str[i]!=0;i++)		/* Send each char of string till the NULL */
	{
		lcddata(str[i]);
	}
}

unsigned char keypad(){
	// make 1st row 0
	PORTC |=   0b11100000;
	PORTC &= ~ 0b00010000;
	if((PIND & (1<<PIND0))==0){
		_delay_ms(10);
		return '1';
		}else if((PIND & (1<<PIND1))==0){
		_delay_ms(10);
		return '2';
		}else if((PIND & (1<<PIND2))==0){
		_delay_ms(10);
		return '3';
	}

	PORTC &= ~ 0b00100000;

	if((PIND & (1<<PIND0))==0){
		_delay_ms(30);
		return '4';
		}else if((PIND & (1<<PIND1))==0){
		_delay_ms(30);
		return '5';
		}else if((PIND & (1<<PIND2))==0){
		_delay_ms(30);
		return '6';
	}

	PORTC &= ~ 0b01000000;

	if((PIND & (1<<PIND0))==0){
		_delay_ms(30);
		return '7';
		}else if((PIND & (1<<PIND1))==0){
		_delay_ms(30);
		return '8';
		}else if((PIND & (1<<PIND2))==0){
		_delay_ms(30);
		return '9';
	}
	
	PORTC &= ~ 0b10000000;

	if((PIND & (1<<PIND0))==0){
		_delay_ms(30);
		return 'C';
		}else if((PIND & (1<<PIND1))==0){
		_delay_ms(30);
		return '0';
		}else if((PIND & (1<<PIND2))==0){
		_delay_ms(30);
		return '=';
	}
}

void i2c_init(){
	TWBR = 0x62;		//	Baud rate is set by calculating
	TWCR = (1<<TWEN);	//Enable I2C
	TWSR = 0x00;		//Prescaler set to 1

}
//Start condition
void i2c_start(){
	TWCR = (1<<TWINT) | (1<<TWEN) | (1<<TWSTA);	//start condition
	while (!(TWCR & (1<<TWINT)));				//check for start condition

}
//I2C stop condition
void i2c_write(char x){				//Cpn esta funcion se escribe en el bus de TWDR
	TWDR = x;						//Move value to I2C
	TWCR = (1<<TWINT) | (1<<TWEN);	//Enable I2C and clear interrupt
	while  (!(TWCR &(1<<TWINT)));
}

char i2c_read(){
	TWCR  = (1<<TWEN) | (1<<TWINT);	//Enable I2C and clear interrupt
	while (!(TWCR & (1<<TWINT)));	//Read successful with all data received in TWDR
	return TWDR;
}


//-----Proto-Type-------//
void lcd_init();			//----LCD Initializing Function
void toggle();				//----Latching function of LCD
void lcd_cmd_hf(char v1);   //----Function to send half byte command to LCD
void lcd_cmd(char v2);		//----Function to send Command to LCD
void lcd_dwr(unsigned char v3);		//----Function to send data to LCD
void lcd_msg(char *c);		//----Function to Send String to LCD
void delay(int ms);			//----Delay function
void lcd_lef_sh();			//----Left Shifting Function
void lcd_rig_sh();			//----Right Shifting Function
//----------------------//

void toggle()
{
	TWDR |= 0x02;					//---PIN En de la LCD en = 1;  -----Latching data in to LCD data register using High to Low signal
	TWCR = (1<<TWINT) | (1<<TWEN);	//---Enable I2C and clear interrupt- Esta linea y la siguiente simepre van despues de querer mandar un coamndo por TDWR
	while  (!(TWCR &(1<<TWINT)));	//---Simepre poner despues de la linea anterior al mandar datos por TWDR
	delay(1);
	TWDR &= ~0x02;					//---PIN del Enable de la LCD en = 0;
	TWCR = (1<<TWINT) | (1<<TWEN);	//---Enable I2C and clear interrupt
	while  (!(TWCR &(1<<TWINT)));
}

void lcd_cmd_hf(char v1)
{
	TWDR &=~0x01;					//PIN RS de la LCD rs = 0; ----Selecting register as Command register
	TWCR = (1<<TWINT) | (1<<TWEN);	//Enable I2C and clear interrupt
	while  (!(TWCR &(1<<TWINT)));
	TWDR &= 0x0F;					//----clearing the Higher 4 bits
	TWCR = (1<<TWINT) | (1<<TWEN);	//Enable I2C and clear interrupt
	while  (!(TWCR &(1<<TWINT)));
	TWDR |= (v1 & 0xF0);			//----Masking higher 4 bits and sending to LCD
	TWCR = (1<<TWINT) | (1<<TWEN);	//Enable I2C and clear interrupt
	while  (!(TWCR &(1<<TWINT)));
	toggle();
}

void lcd_cmd(char v2)
{
	TWDR&=~0x01;					//rs = 0; ----Selecting register as command register
	TWCR = (1<<TWINT) | (1<<TWEN);	//Enable I2C and clear interrupt
	while  (!(TWCR &(1<<TWINT)));
	TWDR &= 0x0F;                   //----clearing the Higher 4 bits
	TWCR = (1<<TWINT) | (1<<TWEN);	//Enable I2C and clear interrupt
	while  (!(TWCR &(1<<TWINT)));
	TWDR |= (v2 & 0xF0);			//----Masking higher 4 bits and sending to LCD
	TWCR = (1<<TWINT) | (1<<TWEN);	//Enable I2C and clear interrupt
	while  (!(TWCR &(1<<TWINT)));
	toggle();
	
	TWDR &= 0x0F;                    //----clearing the Higher 4 bits
	TWCR = (1<<TWINT) | (1<<TWEN);	//Enable I2C and clear interrupt
	while  (!(TWCR &(1<<TWINT)));
	TWDR |= ((v2 & 0x0F)<<4);		//----Masking lower 4 bits and sending to LCD
	TWCR = (1<<TWINT) | (1<<TWEN);	//Enable I2C and clear interrupt
	while  (!(TWCR &(1<<TWINT)));
	toggle();
}

void lcddata(unsigned char data){
	PORTA |= (1<<RS); //RS=1 for data
	PORTA &= ~(1<<RW); //RW=0 for write
	LCD= data & 0xF0;  //Send upper nibble
	PORTD|= (1<<EN); //EN=1 for H to L pulse
	_delay_ms(5);
	PORTD &= ~(1<<EN); // EN=0 for H to L pulse

	LCD = data<<4; // send low nibble;
	PORTD |=(1<<EN); //EN=1 for H to L pulse
	_delay_ms(5);
	PORTD &= ~(1<<EN);
	
}


void lcd_dwr(unsigned char v3)
{
	TWDR|=0x01;						//rs = 1; ----Selecting register as command register
	TWCR = (1<<TWINT) | (1<<TWEN);	//Enable I2C and clear interrupt
	while  (!(TWCR &(1<<TWINT)));
	TWDR &= 0x0F;				    //----clearing the Higher 4 bits
	TWCR = (1<<TWINT) | (1<<TWEN);	//Enable I2C and clear interrupt
	while  (!(TWCR &(1<<TWINT)));
	TWDR |= (v3 & 0xF0);			//----Masking higher 4 bits and sending to LCD
	TWCR = (1<<TWINT) | (1<<TWEN);	//Enable I2C and clear interrupt
	while  (!(TWCR &(1<<TWINT)));
	toggle();
	
	TWDR &= 0x0F;					//----clearing the Higher 4 bits
	TWCR = (1<<TWINT) | (1<<TWEN);	//Enable I2C and clear interrupt
	while  (!(TWCR &(1<<TWINT)));
	TWDR |= ((v3 & 0x0F)<<4);		//----Masking lower 4 bits and sending to LCD
	TWCR = (1<<TWINT) | (1<<TWEN);	//Enable I2C and clear interrupt
	while  (!(TWCR &(1<<TWINT)));
	toggle();
}

void lcd_init()
{
	lcd_cmd_hf(0x30);       //-----Sequence for initializing LCD
	lcd_cmd_hf(0x30);       //-----     "            "              "               "
	lcd_cmd_hf(0x20);       //-----     "            "              "               "
	lcd_cmd(0x28);          //-----Selecting 16 x 2 LCD in 4Bit mode
	lcd_cmd(0x0C);          //-----Display ON Cursor OFF
	lcd_cmd(0x01);          //-----Clear display
	lcd_cmd(0x06);          //-----Cursor Auto Increment
	lcd_cmd(0x80);          //-----1st line 1st location of LCD
}

void delay(int ms)
{
	int i,j;
	for(i=0;i<=ms;i++)
	for(j=0;j<=120;j++);
}

void lcd_msg(char *c)
{
	int i;
	for(i=0;c[i]!=0;i++)		/* Send each char of string till the NULL */
	{
		lcd_dwr(c[i]);
	}
}

void lcd_rig_sh()
{
	lcd_cmd(0x1C);      //----Command for right Shift
	delay(400);
}

void lcd_lef_sh()
{
	lcd_cmd(0x18);      //----Command for Left Shift
	delay(200);
}

//ultra sonic

static volatile unsigned int tCount = 0;// Variable to hold the counter value from TCNT1.
static volatile int i = 0; //Variable to indicate the state of ultrasonic sensor. i = 1 mean sensor is measuring the distance.
double distance = 0;// A variable to store the measured distance in cm

void HCSR04()

{
	
	//Initialize the USART.Remove this part from final code if not needed
	UBRRH=0x00;
	
	UBRRL=51;
	
	DDRB = DDRB | 1 << DDB4; // Set LED pin as an output. Change this according to your circuit
	DDRD = DDRD | 1 << DDD4; // Set Trigger pin as an output. Change this according to your circuit
	DDRD = DDRD & ~(1 << DDD3); // Set Echo pin(INT0 - PD2 on atmega32) as an input.
	PORTD = PORTD & ~(1 << PD3); //Disable pull-up resistor for echo pin. Read from page number 49
	_delay_ms(50);

	GICR |= 1<<INT1; //Enable interrupt for INT0 (Page number 67), For other pins change 0 to 1 or 2. See UltrasonicHCSR04v1.pdf
	MCUCR |= 1<<ISC10;// Make any logical change on INT0 generate an interrupt. (Page number 67)
	TIMSK |= 1 << TOIE1;// Enable Timer/Counter 1, Overflow interrupt. (Page number 112).
	
	sei();
	//_delay_ms(1000);

	while(1){
		
		//Send a 15us pulse to the trigger pin
		PORTD = PORTD | 1<<PD4;
		_delay_us(15);
		PORTD = PORTD & ~(1<<PD4);
		_delay_us(15);
		//Then echo pin will go hight. That interrupt will cause function ISR(INT0_vect) to get executed for the first time.
		//After detecting reflected sound wave, echo pin will go low. That interrupt will cause function ISR(INT0_vect) to get executed for the second time.
		//If echo pin didn't go low before the counter count to 65 535. Counter will overflow and that interrupt will cause ISR(TIMER1_OVF_vect) function to get executed.
		
		distance = tCount*1000000.0/F_CPU/58;
		
		
		//Turn on or off the LED based on the condition
		if (distance < 15)
		{
			PORTB = PORTB | 1 << PB4;
			
			lcd_cmd(0x01);
			lcd_msg("Check coco water");
			_delay_ms(1200);
			lcd_cmd(0xC0);
			//lcd_cmd(0x01);
			lcd_msg("---THANK YOU---");
			//_delay_ms(1200);
			//lcd_cmd(0x01);
		}
		else
		{
			_delay_ms(1200);
			PORTB = PORTB & ~ (1 << PB4);
			lcd_cmd(0x01);
			lcd_msg("---THANK YOU---");
			//_delay_ms(1200);
			//lcd_cmd(0x01);
		}
		_delay_ms(200);
	
	}
	
}

ISR(INT1_vect)// This function will get executed whenever the micro controller is interrupted by INT0.
{
	if(i == 0)//This part get executed when interrupted by a rising edge(for the first time, since i = 0)
	{
		TCCR1B |= 1<<CS10;//Start counting(No prescaling). See page number 110
		i = 1;// So in next interrupt false part will get executed
	}
	else//This part get executed when interrupted by the falling edge(for the second time, since we set i = 1 previously)
	{
		TCCR1B = 0;// Stop counting
		tCount = TCNT1;// Take the value of counter to our variable
		TCNT1 = 0;// Reset counter to 0
		i = 0; // So in next interrupt true part will get executed
	}
}

ISR(TIMER1_OVF_vect){// This function will get executed if Timer/counter 1 get overflowed
	TCCR1B = 0;// Stop counting
	tCount = 200;// This will make the variable ~0 when there is a counter overflow
	TCNT1 = 0;// Reset counter to 0
	i = 0;// So in next interrupt true part will get executed in ISR(INT0_vect) function
}
void servo1(){
	PORTA &= ~ (1<<4);
	
	//Rotate Motor to 0 degree
	PORTA |= 0x10;
	_delay_us(1000);
	PORTA &= ~ 0x10;
	_delay_ms(2000);
	
	//Rotate Motor to 90 degree
	PORTA |= 0x10;
	_delay_us(1500);
	PORTA &=~  0x10;
	
	_delay_ms(2000);
	//Rotate Motor to 90 degree
	
	
}

void servo2(){
	PORTA &= ~ (1<<4);
	
	
	PORTA |= 0x30;
	
	_delay_us(1000);
	PORTA &= ~0x30;
	_delay_ms(2000);
	
	//Rotate Motor to 90 degree
	PORTA |= 0x30;
	_delay_us(1500);
		PORTA &=~ 0x30;
	

}

void DC1()
{
	PORTA |= 0x01;
}
void stopDC()
{
	
	PORTA &=~ (1<<0);
	PORTA &=~ (1<<2);
	PORTA &=~ (1<<1);
	PORTA &=~ (1<<3);
	
}
void DC2()
{
	PORTA |= (1<<0);
	PORTA |= (1<<2);
}
void DC3time()
{
	for (int i=0;i<6;i++)
	{
		PORTA |= 0b01000000;
	}
	_delay_ms(1000);
	PORTA &=~ (1<<6);
	PORTA &=~ (1<<7);
	
}
